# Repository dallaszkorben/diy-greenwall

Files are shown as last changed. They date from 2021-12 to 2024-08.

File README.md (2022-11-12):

# diy-greenwall

<table>
<tr>
<td>

[Before you start](Wiki/BeforeYouStart/beforeYouStart.md)
	
The Green Wall consist of many elements: 					
* Plants in the Balcony Planter Box mounted on the wall
* Irrigation system
* [Sensor Station](Wiki/SensorStation/sensorStation.md)s for measuring water level, temperature, humidity, air pressure
* Camera Station
* Lamp Pump Station
* [Central Access Point](Wiki/CentralAccessPoint/centralAccessPoint.md)
* [3D printed accessories](Wiki/3D/3d.md)
			
</td>
<td>
 
</td>
</tr>	
</table>

---

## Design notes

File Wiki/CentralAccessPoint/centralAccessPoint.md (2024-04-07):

# Central Access Point
The Central Access Point is running on a Raspberry Pi Zero W

## Network configuration

### Install necessary SWs

```sh
    $ sudo apt update
    $ sudo apt full-upgrade
```
```sh
    # dnsmasq - This program has extensive features, but for our purposes we are using it as a DHCP server for our WiFi AP.
    # hostapd - This program defines our AP’s physical operation based on driver configuration. 

    $ sudo apt-get install dnsmasq hostapd     	
```
Install grafana
Ubuntu and Debian(ARMv6): https://grafana.com/grafana/download/9.3.6?edition=enterprise&platform=arm
```sh
    sudo apt-get install -y adduser libfontconfig1 musl
    wget https://dl.grafana.com/enterprise/release/grafana-enterprise-rpi_9.3.6_armhf.deb
    sudo dpkg -i grafana-enterprise-rpi_9.3.6_armhf.deb
```
Config file: /etc/grafana/grafana.ini 

Install sqlite plugin
```sh
    grafana-cli plugins install frser-sqlite-datasource
```

Enable and Start grafana
```sh
    sudo /bin/systemctl enable grafana-server
    sudo /bin/systemctl start grafana-server
```

### Configurations

  * Check the existing network  
    This is what you can see before configuring
    ```sh
    pi@raspberrypi:~$ iw dev
    phy#0
        Unnamed/non-netdev interface
                wdev 0x4
                addr ba:27:eb:07:28:1f
                type P2P-device
                txpower 31.00 dBm
        Interface wlan0
                ifindex 2
                wdev 0x1
                addr b8:27:eb:ff:ff:ff
                ssid <YOUR HOME SSID> 
                type managed
                channel 1 (2437 MHz), width: 20 MHz, center1: 2437 MHz
                txpower 31.00 dBm
    ```
  * Configure dnsmasq  
Let’s call our new interface for AP to uap0
Here we can define the IP interval what we use for the nodes connecting to this AP. In this case it will be between 192.168.50.50 and 192.168.50.150
    ```sh
    pi@raspberrypi:~$ /etc/dnsmasq.conf
      interface=lo,uap0
      no-dhcp-interface=lo,wlan0
      bind-interfaces
      server=8.8.8.8
      domain-needed
      bogus-priv
      dhcp-range=192.168.50.50,192.168.50.150,24h
    ```

  * Configure hostapd  
Here the channel is hardcoded. There is a dynamic and better way to find out the right channel.
I’ll show it later
    ```sh
    pi@raspberrypi:~$ vi /etc/hostapd/hostapd.conf
      interface=uap0
      ssid=Central-Station-006 
      hw_mode=g 
      channel=1 
      macaddr_acl=0 
      auth_algs=1 
      ignore_broadcast_ssid=0 
      wpa=2 
      wpa_passphrase=viragfal 
      wpa_key_mgmt=WPA-PSK 
      wpa_pairwise=TKIP 
      rsn_pairwise=CCMP
    ```  

  * Configure wifi network interface file
    ```sh
     pi@raspberrypi:~$ vi /etc/wpa_supplicant/wpa_supplicant.conf

       ctrl_interface=DIR=/var/run/wpa_supplicant GROUP=netdev 
       update_config=1 

       network={ 
	       ssid="****" 
	       psk="****" 
	       key_mgmt=WPA-PSK 
	       id_str="AP1" 
       } 

       network={ 
	       ssid="****" 
	       psk="****" 
	       key_mgmt=WPA-PSK 
	       id_str="AP2" 
       }
 
  * Configure AP interface file
    ```sh       
     pi@raspberrypi:~$ vi /etc/network/interfaces
       source-directory /etc/network/interfaces.d 

       auto lo 
       auto uap0 
       auto wlan0 

       iface lo inet loopback 

       allow-hotplug uap0 
       iface uap0 inet static 
	       address 192.168.50.3 
	       netmask 255.255.255.0 
	       hostapd /etc/hostapd/hostapd.conf 

       allow-hotplug wlan0 
       iface wlan0 inet manual 
	       wpa-roam /etc/wpa_supplicant/wpa_supplicant.conf 

       iface AP1 inet dhcp 
       iface AP2 inet dhcp
     ```
  * Script to put all together
    ```sh
     pi@raspberrypi:~$ /usr/local/bin/hostapdstart.sh
       #!/bin/bash 

       mac=`sudo ifconfig |grep ether | sed 's/ether \([a-f0-9][a-f0-9]:[a-f0-9][a-f0-9]:[a-f0-9][a-f0-9]:[a-f0-9][a-f0-9]:[a-f0-9][a-f0-9]:[a-f0-9][a-f0-9]\).*/\1/g' | head -n 1` 

       sudo /sbin/iw phy phy0 interface add uap0 type __ap 
       sudo /bin/ip link set uap0 address $mac 

       sudo ifdown --force wlan0 
       sudo ifdown --force uap0 

       sudo ifup uap0 
       sudo ifup wlan0 

       # Fetch wifi channel 
       CHANNEL=`iwlist wlan0 channel | grep Current | sed 's/.*Channel \([0-9]*\).*/\1/g'` 
       export CHANNEL 

       # Create the config for hostapd 
       #cat /etc/hostapd/hostapd.conf.tmpl | envsubst > /etc/hostapd/hostapd.conf 

       # Uncomment the two following lines to get access to internet 
       #sysctl net.ipv4.ip_forward=1 
       #iptables -t nat -A POSTROUTING -s 192.168.50.0/24 ! -d 192.168.50.0/24 -j MASQUERADE 

       sudo systemctl restart hostapd 
       sleep 10 
       sudo systemctl restart dnsmasq 
       sleep 10 
       sudo systemctl restart dhcpcd
    ```
  * unmask hostapd
    ```sh
       pi@raspberrypi:~$ sudo systemctl unmask hostapd
       pi@raspberrypi:~$ sudo systemctl enable hostapd
       pi@raspberrypi:~$ sudo systemctl start hostapd
    ```
  * Run the script just after the reboot automatically  
    In the **crontab** file:
    ```sh
    root@raspberrypi:~$ crontab -e
       @reboot /usr/local/bin/hostapdstart.sh
    ```
  * Check the existing network after the configuration  
    You can see the new Interface: uap0
    ```sh
    root@raspberrypi:~# iw dev
       phy#0 
	       Unnamed/non-netdev interface 
		       wdev 0x3 
		       addr ba:27:eb:97:d5:fe 
		       type P2P-device 
		       txpower 31.00 dBm 
	       Interface uap0 
		       ifindex 3 
		       wdev 0x2 
		       addr b8:27:eb:97:d5:fe 
		       ssid Central-Station-006 
		       type AP 
		       channel 1 (2412 MHz), width: 20 MHz, center1: 2412 MHz 
		       txpower 31.00 dBm 
		       
               Interface wlan0
	               ifindex 2
                       wdev 0x1
                       addr b8:27:eb:ff:ff:ff
                       ssid <YOUR HOME SSID> 
                       type managed
                       channel 1 (2437 MHz), width: 20 MHz, center1: 2437 MHz
                       txpower 31.00 dBm		      
    ```

    ```sh
    root@raspberrypi:~# ip addr 
       1: lo: <LOOPBACK,UP,LOWER_UP> mtu 65536 qdisc noqueue state UNKNOWN group default qlen 1000 
	       link/loopback 00:00:00:00:00:00 brd 00:00:00:00:00:00 
	       inet 127.0.0.1/8 scope host lo 
		       valid_lft forever preferred_lft forever 
	       inet6 ::1/128 scope host
		       valid_lft forever preferred_lft forever 
       2: wlan0: <BROADCAST,MULTICAST,UP,LOWER_UP> mtu 1500 qdisc pfifo_fast state UP group default qlen 1000 
	       link/ether b8:27:eb:97:d5:fe brd ff:ff:ff:ff:ff:ff 
	       inet 192.168.0.103/24 brd 192.168.0.255 scope global dynamic wlan0 
		       valid_lft 1966sec preferred_lft 1966sec 
	       inet6 fdaa:bbcc:ddee:0:ba27:ebff:fe97:d5fe/64 scope global dynamic mngtmpaddr
		       valid_lft 2006054648sec preferred_lft 2006054648sec 
	       inet6 fe80::ba27:ebff:fe97:d5fe/64 scope link
		       valid_lft forever preferred_lft forever 
       3: uap0: <BROADCAST,MULTICAST,UP,LOWER_UP> mtu 1500 qdisc pfifo_fast state UP group default qlen 1000 
	       link/ether b8:27:eb:97:d5:fe brd ff:ff:ff:ff:ff:ff 
	       inet 192.168.50.3/24 brd 192.168.50.255 scope global uap0 
		       valid_lft forever preferred_lft forever 
	       inet6 fe80::ba27:ebff:fe97:d5fe/64 scope link
		       valid_lft forever preferred_lft forever

### Configuration hierarchy

```mermaid
graph LR
/var/spool/cron/crontabs/root --> /home/pi/Projects/diy-greenwall/Software/Central.AccessPoint-RaspberryPi/python/start
/var/spool/cron/crontabs/root --> /usr/local/bin/hostapdstart.sh

/usr/local/bin/hostapdstart.sh --> /etc/dnsmasq.conf
/usr/local/bin/hostapdstart.sh --> /etc/network/interfaces

/etc/network/interfaces --> /etc/hostapd/hostapd.conf
/etc/network/interfaces --> /etc/wpa_supplicant/wpa_supplicant.conf

  ```

---
## Controller software

### Create virtual environment for Python
```sh
pi@raspberrypi:~ $ sudo apt install python3-venv
pi@raspberrypi:~ $ cd /var/www/greenwall/python
pi@raspberrypi:/var/www/greenwall/python $ python3 -m venv env  
```

### Install prerequisites

  ```sh
  pi@raspberrypi:~ $ sudo apt-get install iptables-persistent

  pi@raspberrypi:~ $ sudo apt-get install libapache2-mod-wsgi-py3
 
  pi@raspberrypi:/var/www/greenwall/python $ source env/bin/activate
  (env) pi@raspberrypi:/var/www/greenwall/python/env/bin $ pip install requests
  (env) pi@raspberrypi:/var/www/greenwall/python/env/bin $ pip3 install python-dateutil 
  (env) pi@raspberrypi:/var/www/greenwall/python/env/bin $ python -m pip install flask
  (env) pi@raspberrypi:/var/www/greenwall/python/env/bin $ pip install Flask-Classful==0.15.0b1
  (env) pi@raspberrypi:/var/www/greenwall/python/env/bin $ pip3 install -U flask-cors
  (env) pi@raspberrypi:/var/www/greenwall/python/env/bin $ pip3 install rpi_lcd
  (env) pi@raspberrypi:/var/www/greenwall/python/env/bin $ pip3 install evdev
  (env) pi@raspberrypi:/var/www/greenwall/python/env/bin $ pip3 install psutil
  (env) pi@raspberrypi:/var/www/greenwall/python/env/bin $ pip install scipy --no-cache-dir
  (env) pi@raspberrypi:/var/www/greenwall/python/env/bin $ pip install matplotlib
  (env) pi@raspberrypi:/var/www/greenwall/python/env/bin $ pip3 install pandas
  (env) pi@raspberrypi:/var/www/greenwall/python/env/bin $ pip3 install natsort

  $ sudo apt-get install python3-sklearn python3-sklearn-lib  
  $ pip3 install opencv-python
  ```
### Clone the diy-greenwall project

First you should clone the diy-greenwall project from the GitHub.
 ```sh
  $ cd
  $ mkdir Projects
  $ git clone https://github.com/dallaszkorben/diy-greenwall.git
 ```
As you need only the hierarcy under the **diy-greenwall/Software/Central.AccessPoint-RaspberryPi** folder, on the Rasberry Pi, you can filter out the not necesary parts. But it is not mandatory to do

```sh
  $ cd diy-greenwall
  $ git  filter-branch -f --subdirectory-filter Software/Central.AccessPoint-RaspberryPi 
```

Under the **python** folder, you can see the following hierarchy of the python code:
  ```sh
  .
  ├── config
  │   ├── config.py
  │   ├── ini_location.py
  │   ├── __init.py__
  │   ├── permanent_data.py
  │   ├── property.py
  │   └── __pycache__
  │       ├── config.cpython-37.pyc
  │       ├── ini_location.cpython-37.pyc
  │       ├── permanent_data.cpython-37.pyc
  │       └── property.cpython-37.pyc
  ├── controlbox
  │   ├── controlbox.py
  │   ├── __init__.py
  │   └── __pycache__
  │       ├── controlbox.cpython-37.pyc
  │       └── __init__.cpython-37.pyc
  ├── exceptions
  │   ├── __init.py__
  │   ├── invalid_api_usage.py
  │   └── __pycache__
  │       └── invalid_api_usage.cpython-37.pyc
  ├── graph
  │   ├── graph_level.py
  │   ├── __init.py__
  │   └── __pycache__
  │       └── graph_level.cpython-37.pyc
  ├── greenwall.wsgi
  ├── ky040
  │   ├── __init__.py
  │   ├── ky040.py
  │   └── __pycache__
  │       ├── __init__.cpython-37.pyc
  │       ├── ky040.cpython-37.pyc
  │       └── KY040.cpython-37.pyc
  ├── restserver
  │   ├── endpoints
  │   │   ├── ep_info_functions.py
  │   │   ├── ep_info_graph.py
  │   │   ├── ep_info_timestamp.py
  │   │   ├── ep_level_add.py
  │   │   ├── ep.py
  │   │   ├── __init.py__
  │   │   ├── __pycache__
  │   │   │   ├── ep.cpython-37.pyc
  │   │   │   ├── ep_info_functions.cpython-37.pyc
  │   │   │   ├── ep_info_graph.cpython-37.pyc
  │   │   │   ├── ep_info_level.cpython-37.pyc
  │   │   │   ├── ep_info_timestamp.cpython-37.pyc
  │   │   │   ├── ep_info_trend.cpython-37.pyc
  │   │   │   ├── ep_level_add.cpython-37.pyc
  │   │   │   └── ep_level_read.cpython-37.pyc
  │   │   ├── representations.py
  │   │   └── ~toDelete
  │   │       └── ep_info_level.py
  │   ├── gradual_thread_controller.py
  │   ├── __init.py__
  │   ├── __pycache__
  │   │   ├── gradual_thread_controller.cpython-37.pyc
  │   │   ├── representations.cpython-37.pyc
  │   │   ├── view_info.cpython-37.pyc
  │   │   ├── view_level.cpython-37.pyc
  │   │   └── ws_greenwall.cpython-37.pyc
  │   ├── representations.py
  │   ├── view_info.py
  │   ├── view_level.py
  │   └── ws_greenwall.py
  ├── start.py
  └── utilities
      ├── __init.py__
      ├── __pycache__
      │   └── report.cpython-37.pyc
      └── report.py  
  ```

### Install Web server on Raspberry Pi
  Apache2 server should be installed and configured to allow browsers to connect and see the statuses of Sensors

  * Find the codes under **web-location/greenwall/** folder
    ```sh
    .
    └── greenwall
        ├── favicon.ico
        ├── /graph-images
        ├── /index.html
        └── /script
            ├── /jquery
            │   └── jquery-3.6.0.min.js
            └── /jquery-ui
                ├── AUTHORS.txt
                ├── /external
                │   └── /jquery
                │       └── jquery.js
                ├── images              
                ├── index.html
                ├── jquery-ui.css
                ├── jquery-ui.js
                ├── jquery-ui.min.css
                ├── jquery-ui.min.js
                ├── jquery-ui.structure.css
                ├── jquery-ui.structure.min.css
                ├── jquery-ui.theme.css
                ├── jquery-ui.theme.min.css
                ├── LICENSE.txt
                └── package.json
    ```
  * Copy the the whole folder to /var/www folder
  
    ```sh
    pi@raspberrypi:~$ cd web-location
    pi@raspberrypi:web-location$ cp -r greenwall /var/www/
    ```

  * Configure available Apach2 config file  
    Alternativaly you can copy the **green-wall.conf** file, found under the **web-config** folder to the **/etc/apache2/conf-available** folder on the Raspberry pi
    ```sh
    pi@raspberrypi:~$ touch /etc/apache2/conf-available/green-wall.conf
     
    WSGIRestrictStdout Off
    WSGIApplicationGroup %{GLOBAL}
    <VirtualHost *:80>
        ServerAdmin webmaster@greenwall.com
        ServerName www.greenwallsite.com
        ServerAlias greenwallsite.com

        ErrorLog /var/www/greenwall/logs/error.log
        CustomLog /var/www/greenwall/logs/access.log combined

        WSGIDaemonProcess greenwall user=pi group=pi threads=5 python-home=/var/www/greenwall/python/env
        WSGIProcessGroup greenwall
        WSGIScriptAlias / /var/www/greenwall/python/greenwall.wsgi    

        <IfModule dir_module>
            DirectoryIndex index.html
        </IfModule>

        Alias /greenwall/ /var/www/greenwall/
        <Directory /var/www/greenwall>
            Order allow,deny
            Allow from all
        </Directory>

    </VirtualHost>
    ```

  * Configure enabled Apach2 config file
    ```sh
    pi@raspberrypi:~$ ln -s /etc/apache2/conf-available/green-wall.conf /etc/apache2/conf-enabled/green-wall.conf      
    ```
  
  * Install mod_wsgi
    ```sh
    pi@raspberrypi:~$ sudo apt-get install libapache2-mod-wsgi python-dev
    ```

  * Enable mod_wsgi
    ```sh
    pi@raspberrypi:~$ sudo a2enmod wsgi 
    ```
      
  * Restart Apach2 service
    ```sh
    ~~pi@raspberrypi:~$ sudo /etc/init.d/apache2 restart~~ 
    pi@raspberrypi:~$ sudo systemctl restart apache2      
    ```

### Services on PI
#### CAM
```mermaid
sequenceDiagram
participant Cam
participant PI
participant WEB browser

    loop CamRegister
        Cam->>PI: POST /cam/register
        PI->>PI: register
    end

    loop AutomaticSaveFrame
        Cam->>PI: POST /cam/save/frame/camId/<camId>
        PI->>PI: save file
    end

    loop GetRegisteredCams
        WEB browser->>PI: GET /cam/captureList
        PI->>WEB browser: gives back the registered cams
    end

    loop SaveCaptureByRequest
        WEB browser->>PI: GET /cam/capture/url
        PI->>Cam: GET /capture
        Cam->>Cam: take photo
        Cam->>PI: send back photo
        PI->>WEB browser: gives back the url to the photo 
    end

    loop GenerateVideoFromFrames
        WEB browser->>PI: POST /cam/construct/video {camId,startDate,endDate,fps}
        PI->>PI: construct the video in the background
    end
  ```

#### LAMP-PUMP
#### SENSORS

### Port forwarding
  Why do we need it?
  Because in  development/test phase I use the stand alone WSGI server to receive REST requests from the Sensor Stations and Control Stations. The stand alone WSGI server uses port 5000.
  
  But later, I use the integrated WSGI in the Apache server, instead of the stand alone WSGI. That means, the port changes to 80. But I do not want to change the code all the time in the Station modules, when I change the WSGI. 
To make it work in both case I have to do a port forwarding. If the Central Controler Unit receive a rest request to port 5000, it should be mapped to port 80 instead.

```sh
    root@raspberrypi:~# echo "1" /proc/sys/net/ipv4/ip_forward
    root@raspberrypi:~# iptables -t nat -A PREROUTING -p tcp -d 192.168.50.3 --dport 5000 -j DNAT --to-destination 192.168.50.3:80
    root@raspberrypi:~# iptables -t nat -A POSTROUTING -j MASQUERADE
```

The firewall should look like this:

```sh
    root@raspberrypi:~# iptables -t nat -L --line-numbers
    Chain PREROUTING (policy ACCEPT)
    num  target     prot opt source               destination         
    1    DNAT       tcp  --  anywhere             192.168.50.3         tcp dpt:5000 to:192.168.50.3:80

    Chain INPUT (policy ACCEPT)
    num  target     prot opt source               destination         

    Chain POSTROUTING (policy ACCEPT)
    num  target     prot opt source               destination         
    1    MASQUERADE  all  --  anywhere             anywhere            

    Chain OUTPUT (policy ACCEPT)
    num  target     prot opt source               destination         
```

Unfortunatelly this settings will disappear after a reset, so you have to make it persistent.
```sh
    root@raspberrypi:~# /sbin/iptables-save > /etc/iptables/rules.v4
    root@raspberrypi:~# cat /etc/iptables/rules.v4
    
    # iptables-persisten was already installed
    # make sure the service is enabled
    root@raspberrypi:~# sudo systemctl is-enabled netfilter-persistent.service
    enabled
    
    # if it is not, then enable it
    root@raspberrypi:~# sudo systemctl enable netfilter-persistent.service
    
    # get status
    sudo systemctl status netfilter-persistent.service

```

---
## ky040 - rotary encoder
  
  To enable/configure the rotary-encoder device tree overlay, simply put something like the following into **/boot/config.txt** (with the encoder connected to pins **5** and **6** on the Raspberry Pi)
  While you’re at it, you might also want to add the middle button as a key (mine is connected to pin **13**):

  * enable rotary encoder
    ```sh       
    pi@raspberrypi:~$ vi /boot/config.txt
       dtoverlay=rotary-encoder,pin_a=5,pin_b=6,relative_axis=1
       dtoverlay=gpio-key,gpio=13,keycode=28,label="ENTER"       
    ```
  After a reboot you’ll have a new device in **/dev/input/** for the rotary encoder. You can use the **evtest** tool (as in evtest /dev/input/event0) to look at the events it generates and confirm that it reacts perfectly to every turn of the encoder, without missing a movement or confusing the direction.

  * Here is an example, shows how to read the output of the rotary encoder.
    ```python
    from __future__ import print_function
    import evdev
    import select

    devices = [evdev.InputDevice(fn) for fn in evdev.list_devices()]
    devices = {dev.fd: dev for dev in devices}
    value = 1
    print("Value: {0}".format(value))
    done = False
    
    while True:
        r, w, x = select.select(devices, [], [])
        for fd in r:
            for event in devices[fd].read():
                event = evdev.util.categorize(event)
                if isinstance(event, evdev.events.RelEvent):
                    value = value + event.event.value
                    print("Value: {0}".format(value))
                elif isinstance(event, evdev.events.KeyEvent):
                    if event.keycode == "KEY_ENTER" and event.keystate == event.key_up:
		        print("Enter")
    ```

---
## 2x16 LCD display
  
  * In the Raspberry Pi run the "Raspberry Pi Configuration" application and undert the "Interfaces" tab, **Enable** the I2C
  * Connect the pins of LCD display to the corresponding pins of RP
    * GND -> GND
    * VCC -> 5V
    * SDA -> SDA1
    * SCL -> SCL1
  * Check th eaddress of the I2C box on the RP
    ```sh         
    pi@raspberrypi:/var/www $ i2cdetect -y 1
         0  1  2  3  4  5  6  7  8  9  a  b  c  d  e  f
    00:          -- -- -- -- -- -- -- -- -- -- -- -- -- 
    10: -- -- -- -- -- -- -- -- -- -- -- -- -- -- -- -- 
    20: -- -- -- -- -- -- -- 27 -- -- -- -- -- -- -- -- 
    30: -- -- -- -- -- -- -- -- -- -- -- -- -- -- -- -- 
    40: -- -- -- -- -- -- -- -- -- -- -- -- -- -- -- -- 
    50: -- -- -- -- -- -- -- -- -- -- -- -- -- -- -- -- 
    60: -- -- -- -- -- -- -- -- -- -- -- -- -- -- -- -- 
    70: -- -- -- -- -- -- -- --                       
    ```

## Wiring

```sh
                                         
   Raspberry PI   LCD    Rotary                                         
   ____________________________                                         
   pin Function                                         
     3 GPIO 2     SDA                                               
     5 GPIO 3     SCL                                                        
     4 5V         VCC                                              
     9 GND        GND                                   Rotary encoder
                                                     _______________
     2 5V                +                          /        _       \
     6 GND               GND                       |     /       \    |
    29 GPIO 5            CLK                       |                  |
    31 GPIO 6            TD                        |    |    o    |   |
    33 GPIO 13           SW                        |                  |
                                                   |     \       /    |
                                                   |         -        |
                                                   |   C           G  |
     Raspberry PI W Zero                           |   L  T  S     N  |
    __________________                             |   K  D  W  +  D  |
   /     |      |     \                            |                  |
  |      |      |      |                           |   o  o  o  o  o  |
  |       ------       |                            \__|__|__|__|__|_/
  |             1  2   |                               |  |  |  |  |
  |             o  o-----------------------------------|--|--|--'  |
  | .-----------o  o------------------------.          |  |  |     |
  | |  .--------o  o-----------------------------------|--|--|-----'
  | | |         o  o   |                    |          |  |  |
  | | | .-------o  o   |             .-----------------'  |  |
  | | | |       o  o   |             |      |             |  |
  | | | |       o  o   |           .----------------------'  |
  | | | |       o  o   |           | |      |                |
  | | | |       o  o   |         .---------------------------'
  | | | |       o  o   |         | | |      |
  | | | |       o  o   |         | | |      |
  | | | |       o  o   |         | | |      |
  | | | |       o  o   |         | | |      |
  | | | |       o  o   |         | | |      |          LCD Display
  | | | | .-----o  o   |         | | |      |     ____________________
  | | | | | .---o  o   |         | | |      |    /      S  S  V  G    \ 
  | | | | | | .-o  o   |         | | |      |   |       C  D  C  N     | 
  | | | | | | | o  o   |         | | |      |   |       L  A  C  D     |
  | | | | | | | o  o   |         | | |      |   |                      |
  | | | | | | | o  o   |         | | |      |   |       o  o  o  o     |
  | | | | | | | 39 40  |         | | |      |   |       |  |  |  |     |
   \|_|_|_|_|_|_______/          | | |      |    \______|__|__|__|____/
    | | | | | |                  | | |      |           |  |  |  |
    | | | | | `------------------' | |      |           |  |  |  |
    | | | | `----------------------' |      |           |  |  |  |
    | | | `--------------------------'      |           |  |  |  |
    | | |                                   |           |  |  |  |
    | | |                                    `----------|--|-'   |
    | | |                                               |  |     |
    | | `-----------------------------------------------|--|----'
    | `-------------------------------------------------'  | 
    `------------------------------------------------------'
```

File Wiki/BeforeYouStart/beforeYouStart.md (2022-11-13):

# Before you start

I'm working on Ubuntu 22.04.1 LTS 
You need to install some things and fix some other things to be able to start

## Arduino

### Install Arduino

```sh
$ sudo apt update
$ sudo apt upgrade
$ mkdir arduino
$ cd arduino/
$ wget https://downloads.arduino.cc/arduino-1.8.15-linux64.tar.xz
$ tar -xvf ./arduino-1.8.15-linux64.tar.xz
$cd arduino-1.8.15/
$ sudo ./install.sh
```

### Add necessary Boards

File > Preferences > Additional Boards Manager URLs:

https://dl.espressif.com/dl/package_esp32_index.json,https://arduino.esp8266.com/stable/package_esp8266com_index.json

### Install necessary Libraries

Tools > Manager Libraries

 * BMP180MI
 * ArduinoJson
 * DHT sensor library
 * Preferences
 * Time

### Fix ttyUSB error

It might happen that when you upload a sketch - after you have selected your board and the serial port -, you get an error Error opening serial port ... If you get this error, you need to set serial port permission.

Check the serial port permission:

```sh
$ ls -l /dev/ttyUSB0
crw-rw---- 1 root dialout 188, 0 Nov 12 21:36 /dev/ttyUSB0
```

You need to add your user to the group

`<username>`: is your Linux user name.

```sh
sudo usermod -a -G dialout <username>
```

You will need to log out and log in again for this change to take effect.
And then you can start the arduino UI again

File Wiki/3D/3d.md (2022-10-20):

# 3D printed accessories

## Flower Container

<p float="left">
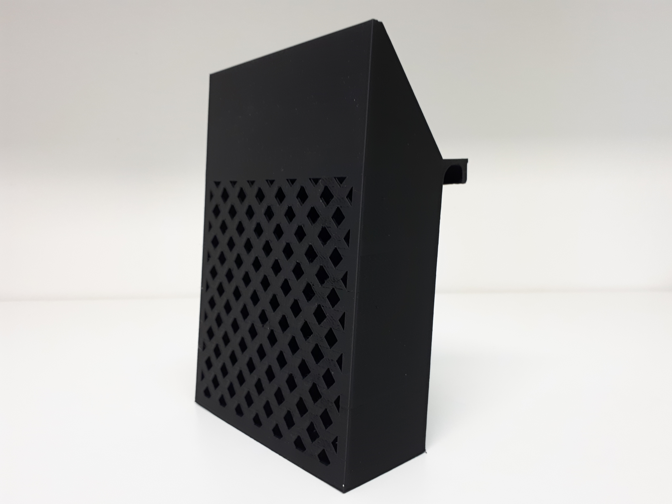
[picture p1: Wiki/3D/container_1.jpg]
    
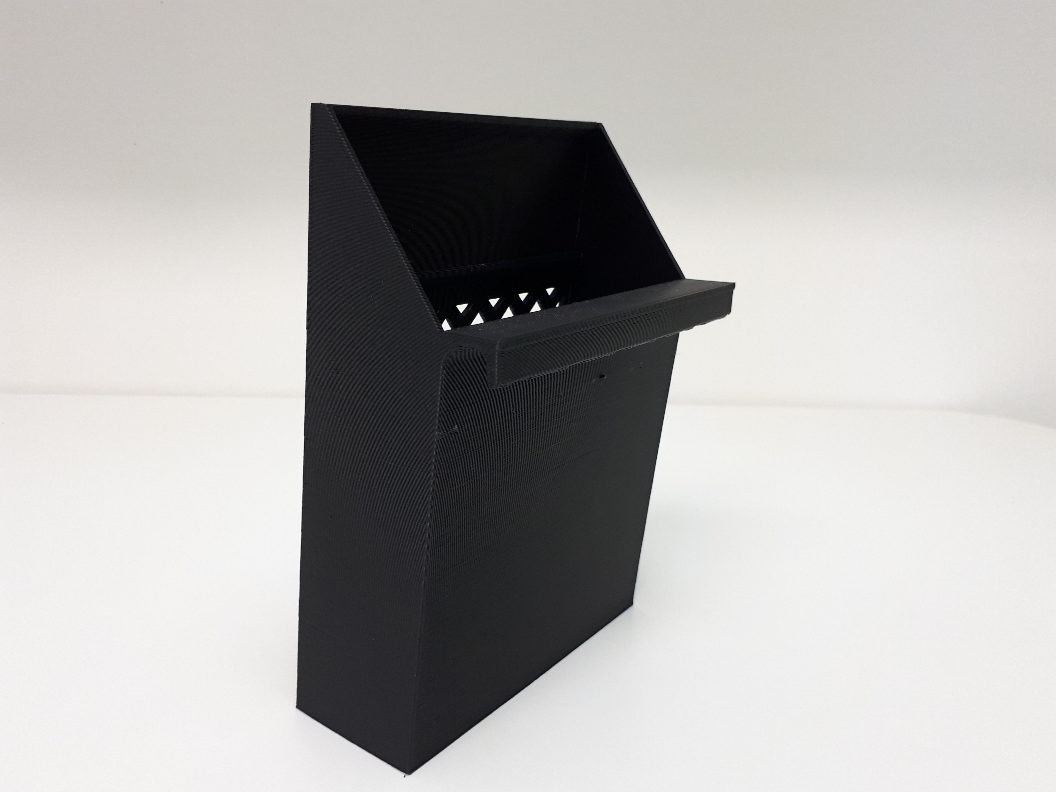
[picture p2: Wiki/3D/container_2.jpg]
    
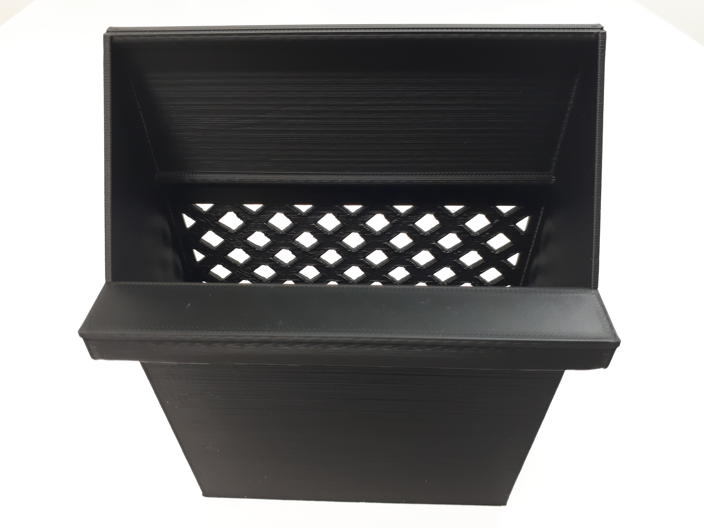
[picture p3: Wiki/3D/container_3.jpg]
    
</p>

## Overflow

## Sensor Station
<p float="left">
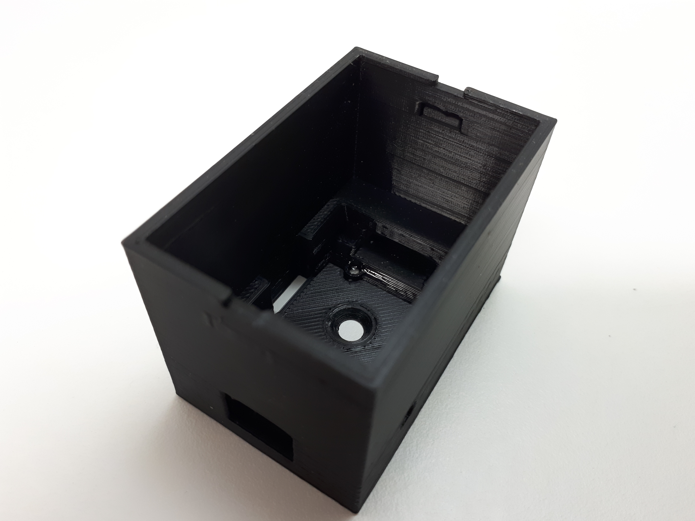
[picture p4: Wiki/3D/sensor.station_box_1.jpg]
    
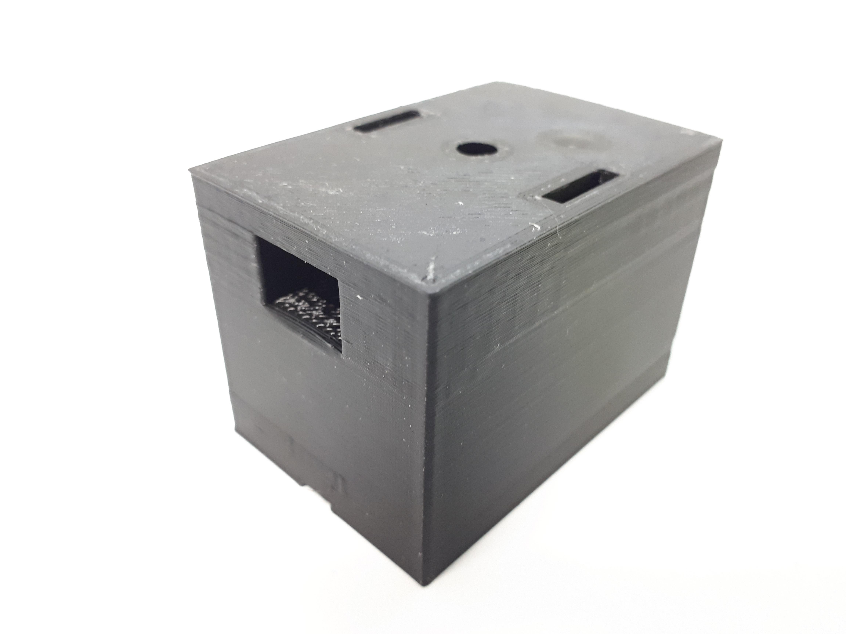
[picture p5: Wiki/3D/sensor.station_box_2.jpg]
    
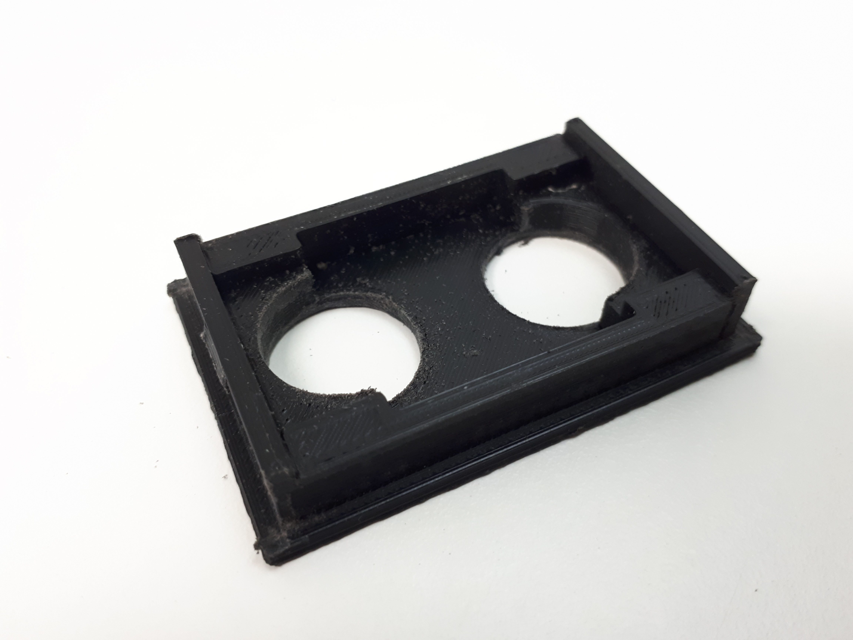
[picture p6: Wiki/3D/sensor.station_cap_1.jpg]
    
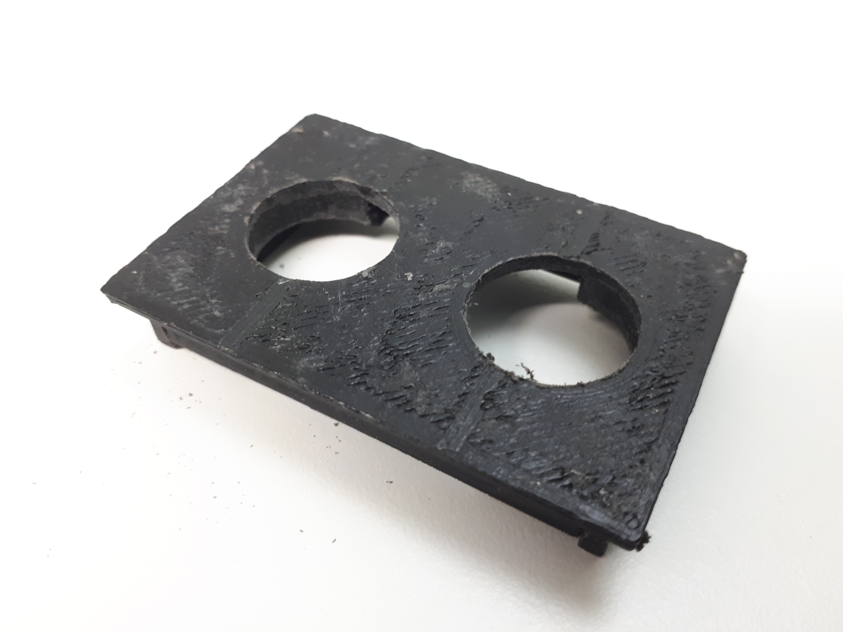
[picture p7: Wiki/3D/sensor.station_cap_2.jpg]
    
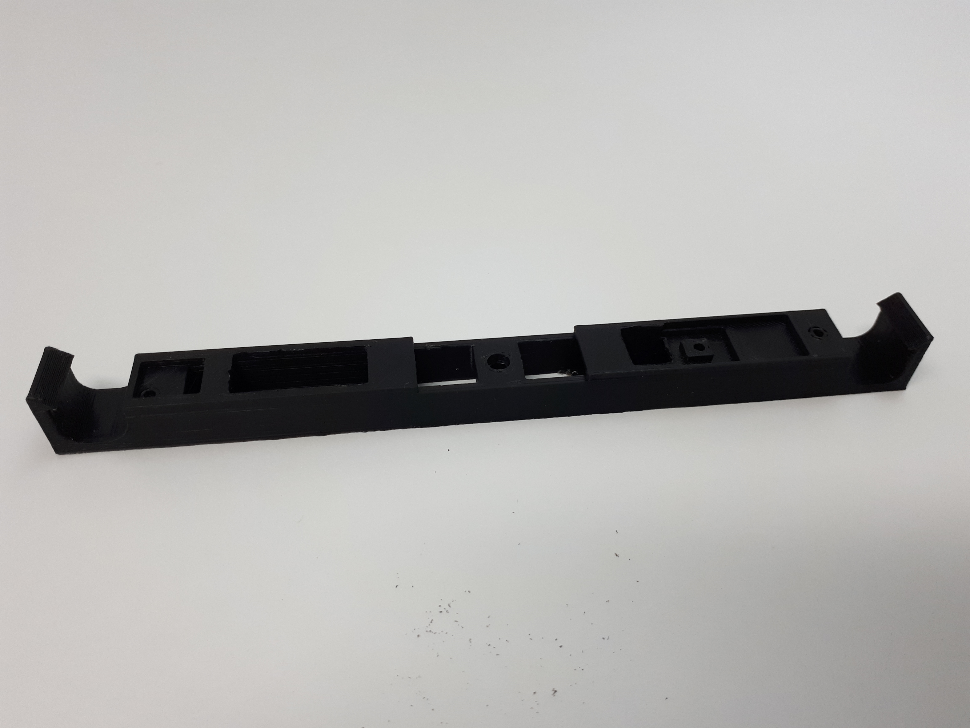
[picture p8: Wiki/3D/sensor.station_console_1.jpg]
    
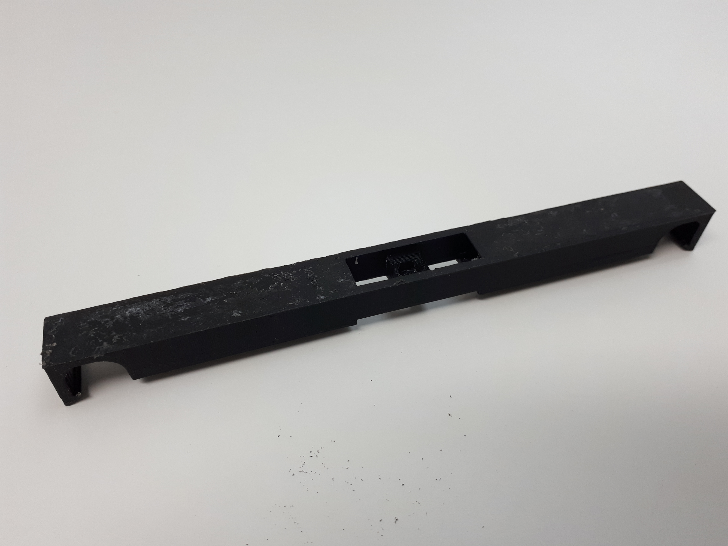
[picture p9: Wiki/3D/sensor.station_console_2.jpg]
    
</p>
<p float="left">
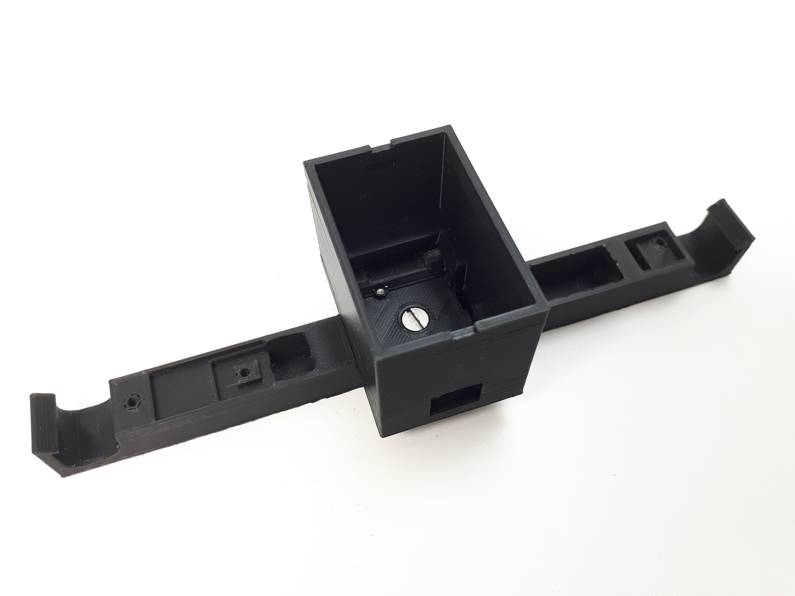
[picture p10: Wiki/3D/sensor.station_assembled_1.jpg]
    
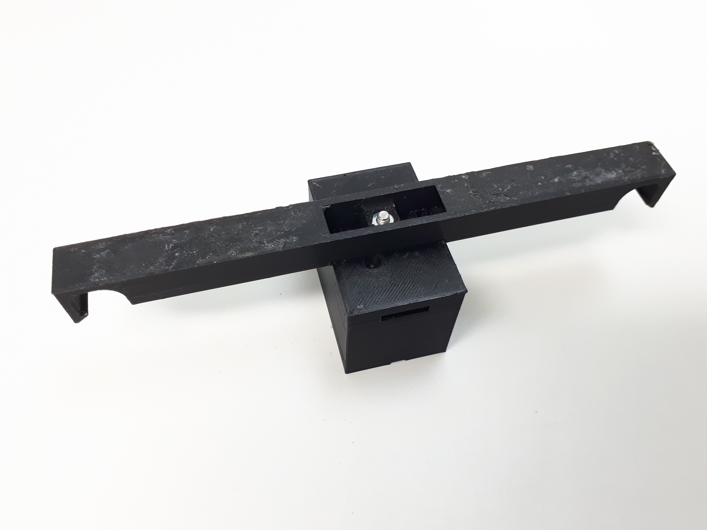
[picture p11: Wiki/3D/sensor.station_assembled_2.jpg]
    
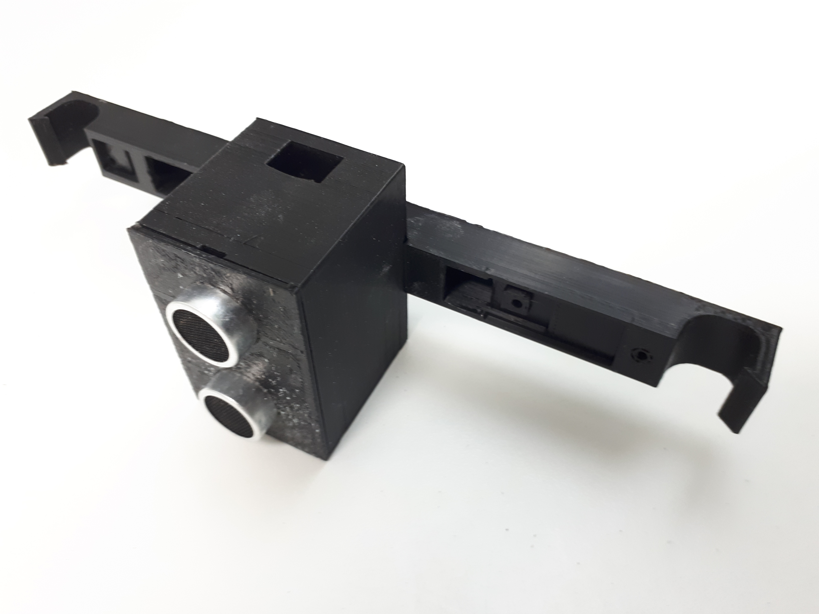
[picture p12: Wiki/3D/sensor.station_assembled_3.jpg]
    
</p>

## Cam Station

## Lamp/Pump Station

## Central Access Point

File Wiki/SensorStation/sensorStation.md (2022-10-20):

# Sensor Station
The Sensor Station units are ESP12F modules with connected sensors.  
The code is written in C under Arduino.  
The code does 4 main things:
 * Runs a Web Server and serves the requests
 * Periodically makes measurements on the sensors, calculates an average value and stores those values. In one loop it makes measurement only on one sensor to reduce time delay.
 * Periodically (configurable) sends the stored values to the server, and then reset the stored values
 * For safety's sake, the module periodically (configurable) resets itself.

## Needed libraries in Arduino

 * DHT sensor library
 * BMP180MI

## Used sensors

 * DHT22 - Temperature/Humidity sensor  
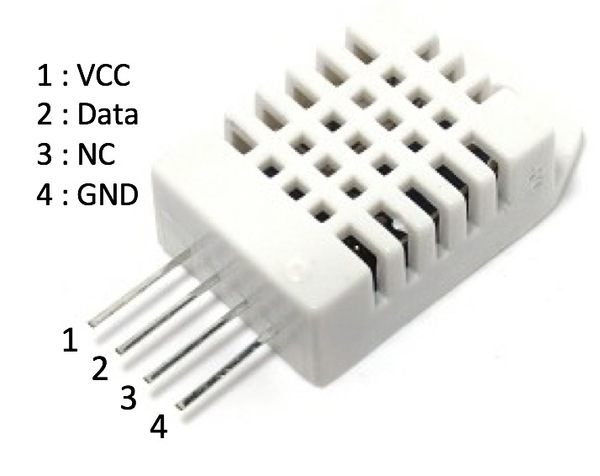
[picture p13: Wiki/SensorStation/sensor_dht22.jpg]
    
 * BMP180 - Barometric Pressure/Temperature sensor  
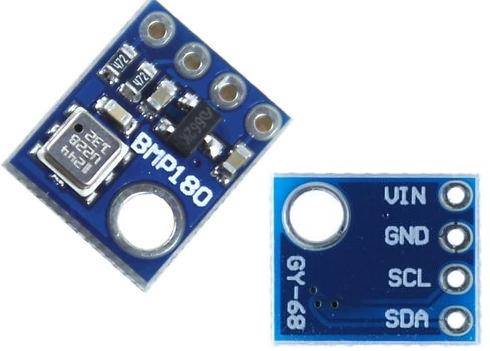
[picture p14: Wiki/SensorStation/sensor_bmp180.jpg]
    
 * HCSR04 - Ultrasonic sensor to measure water level  
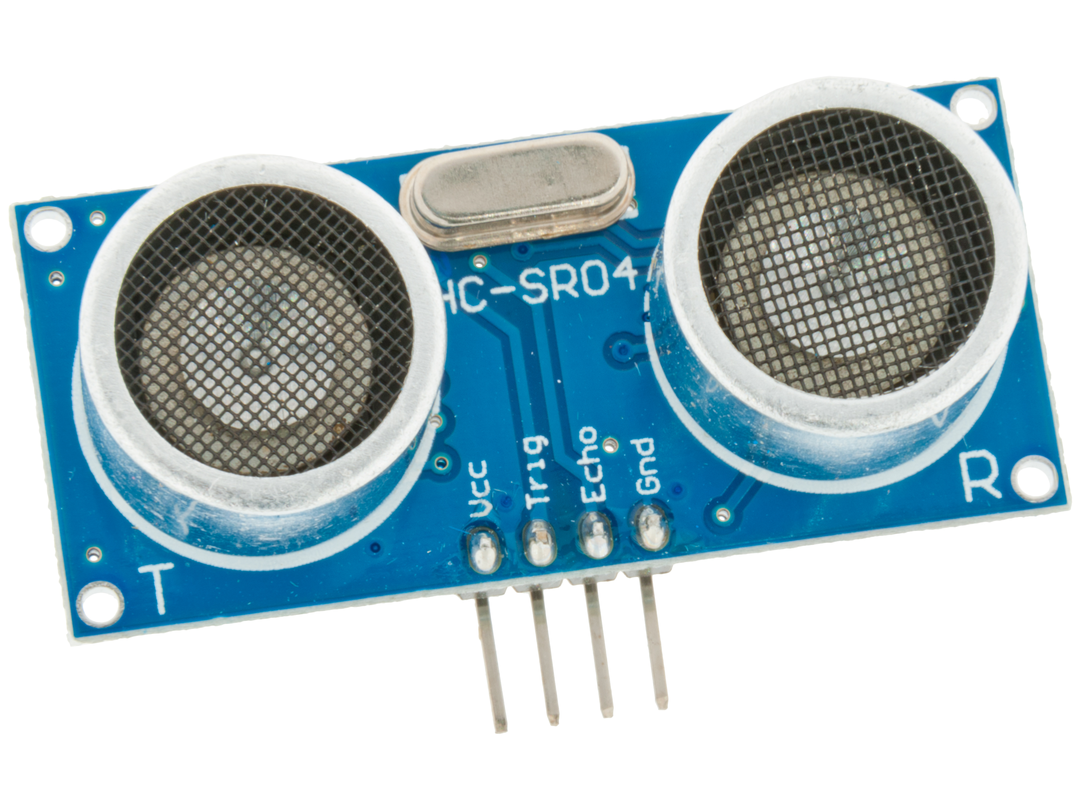
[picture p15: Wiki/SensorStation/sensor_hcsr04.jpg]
    

## WebServer entry points
You can send direct REST requests to the SensorStation

### GET /configure
Gives back the configuration collection in json format
```sh
pi@raspberrypi:~ $ curl -s --request GET http://192.168.50.101:80/configure
{"stationId": "default","sensorTempHumOutGPIO": "0","sensorDistanceTrigGPIO": "12","sensorDistanceEchoGPIO": "14","intervalReportMillis": "600300","intervalRegisterMillis": "120600",}
```

### POST /configure
Sets values of the configuration collection.
You can provide all values or a sub-set of the values in the json format
```sh
curl  --header "Content-Type: application/json" --request POST --data '{"stationId": "default","sensorTempHumOutGPIO": "0","sensorDistanceTrigGPIO": "12","sensorDistanceEchoGPIO": "14","intervalReportMillis": "600300","intervalRegisterMillis": "120600",}' http://192.168.50.101:80/configure
```

### GET /temperature
Measure the temperature - taking 1 sample only - on all connected termometer (BMP180/DHT22), and gives back the calculated average value in json format
If no termometer sensor connected, it gives back EMPTY ("") value
```sh
pi@raspberrypi:~ $ curl -s --request GET http://192.168.50.101:80/temperature
{"temperature": "24.15"}
```

### GET /humidity
Measure the humidity (DHT22) - taking 1 sample only - and gives back it in json format.
If the humidity sensor is not connected, it gives back EMPTY ("") value
```sh
pi@raspberrypi:~ $ curl -s --request GET http://192.168.50.101:80/humidity
{"humidity": "45.00"}
```

### GET /pressure
Measure the pressure (BMP180) - taking 1 sample only - and gives back it in json format.
If the pressure sensor is not connected, it gives back EMPTY ("") value
```sh
pi@raspberrypi:~ $ curl -s --request GET http://192.168.50.101:80/pressure
{"pressure": "102545.00"}
```

### GET /distance
Measure the distance (HCSR04) - taking 1 sample only - and gives back it in json format.
If the  sonar sensor is not connected, it gives back EMPTY ("") value
```sh
pi@raspberrypi:~ $ curl -s --request GET http://192.168.50.101:80/distance
{"distance": "7.21"}
```

### GET /all/actual
Measures all measurable quntities, from the connected sensors, and gives back the results in one request
```sh
pi@raspberrypi:~ $ curl -s --request GET http://192.168.50.101:80/all/actual
{"temperature": "24.20","humidity": "45.70","pressure": "102549.00","distance": "7.62",}
```

### GET /all/aggregated
The ESP module continously collects all measurable quantities from the sensors, calculates the average values and store them.
This request gives back the stored average values. The point is that in this request there is NO measurement.
```sh
pi@raspberrypi:~ $ curl -s --request GET http://192.168.50.101:80/all/aggregated
{"temperature": "24.17","humidity": "45.92","pressure": "102546.05","distance": "7.27",}
```

## Wiring

```sh
ESP12F       | DHT22  BMP180  HCSR04                           
             |                                                       
pin Function |                                       
_____________|______________________
 D3 GPIO 0   | OUT                                               
             |                                                         
 D2 GPIO 4   |        SDA                                       
 D1 GPIO 5   |        SCL                     
             |                                
 D5 GPIO 14  |                ECHO            
 D6 GPIO 12  |                TRIG            

    HCSR04                      ESP12F                             BMP180
 .----------.           .---------------------.
 |          |           |    || |_| |_| |     |               .--------------.
 |          |           | o  ||         |TX o |               |              |
 |          |           | o   .--------.    o |               | o VIN     O  |
 |   GND  o------.      | o   |        |    o |       .---------o GND        |
 |   Echo o---------------o D5|        |D01 o---------|---------o SCL  .---. |
 |   Trig o---------------o D6|        |D02 o---------|---------o SDA  |   | |
 |   Vcc  o----. |      | o   |        |D03 o---------|--.    |        `---' |
 |          |  | |      | o   .--------'GND o---------.  |    `--------------'
 |          |  | | .------o 3.3V        5V  o----.    |  |
 |          |  | | |    |                     |  |    |  |         DHT22
 |          |  | | |    |                     |  |    |  |    . -------------.
 `----------'  | | |    `---------------------'  |    |  |    |           |   \
               | | `-----------------------------|----|--|------o +       |    \
               `---------------------------------'    |  `------o Out     | O  | 
                 `------------------------------------`---------o -       |    /
                                                              |           |   /
                                                              `--------------'

```

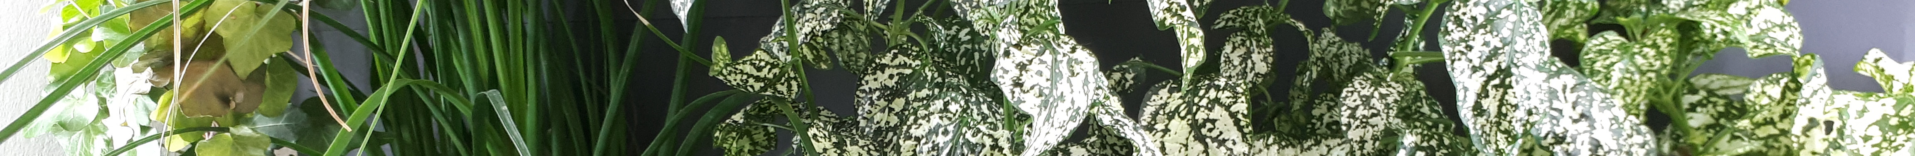
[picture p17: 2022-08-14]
Software/Central.AccessPoint-RaspberryPi/var/www/greenwall/header.jpg

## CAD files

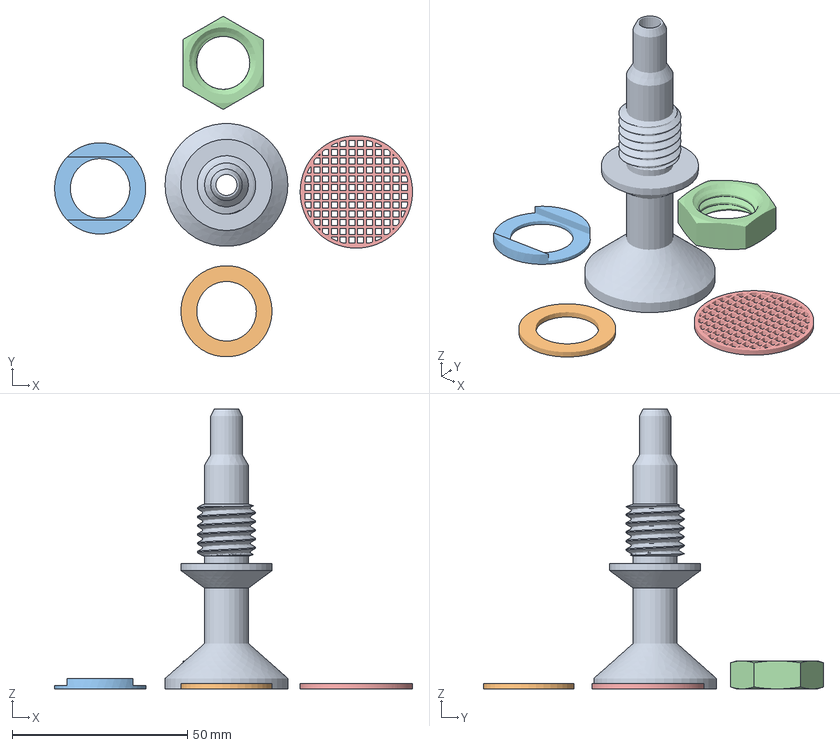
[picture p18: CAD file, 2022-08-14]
3D/STL/owerflow/overflow.plug.full.amf
102.0 x 97.0 x 79.7 mm
Nut-R=9,003

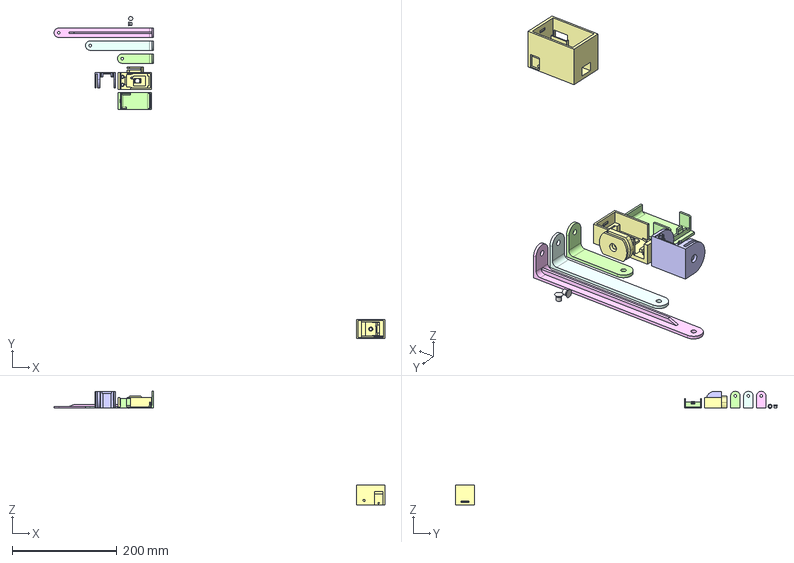
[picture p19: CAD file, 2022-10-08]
3D/FREECAD/camera/camera.wroover.nested.FCStd
631.3 x 614.5 x 216.7 mm

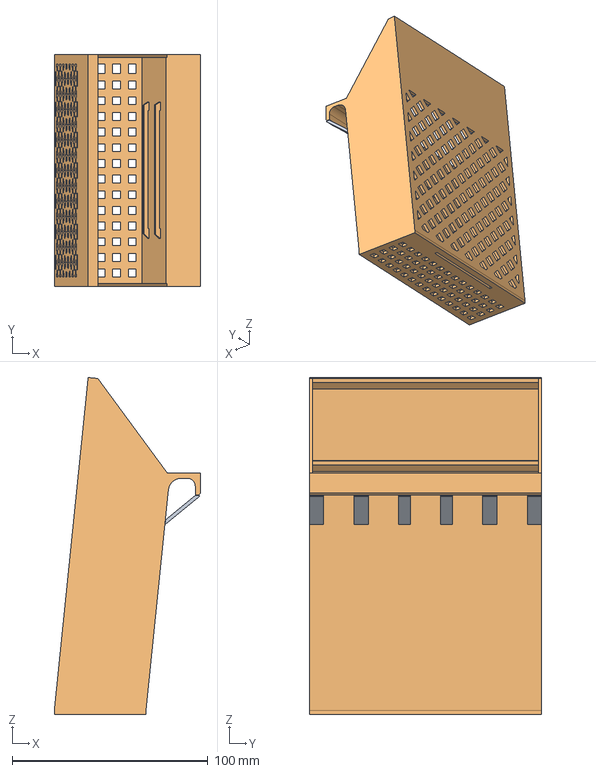
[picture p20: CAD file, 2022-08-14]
3D/FREECAD/container/container-vertical.FCStd
74.8 x 118.7 x 172.0 mm

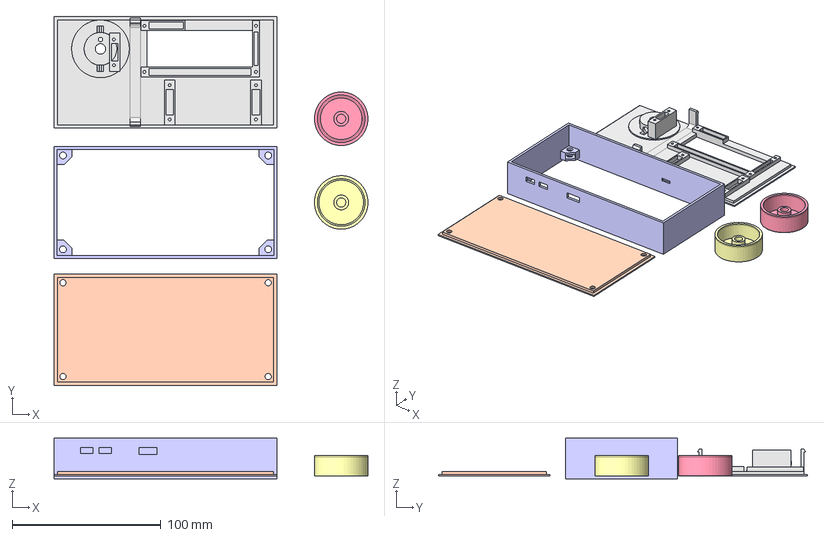
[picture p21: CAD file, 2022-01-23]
3D/FREECAD/control.box/controlbox.FCStd
211.1 x 248.0 x 27.5 mm

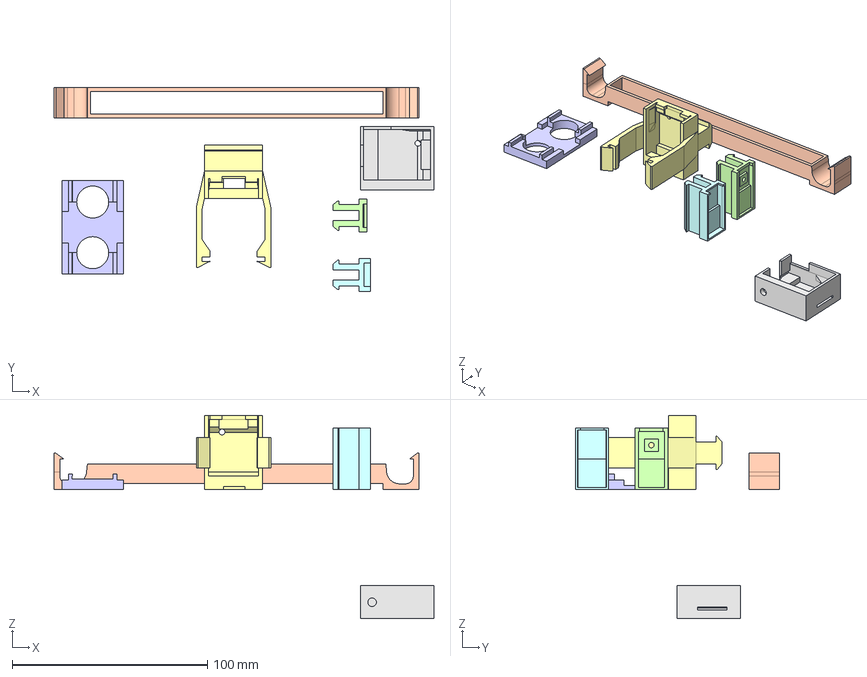
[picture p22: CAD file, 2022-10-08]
3D/FREECAD/hanger.station.V2.FCStd
194.8 x 104.6 x 104.1 mm
Rectangle002

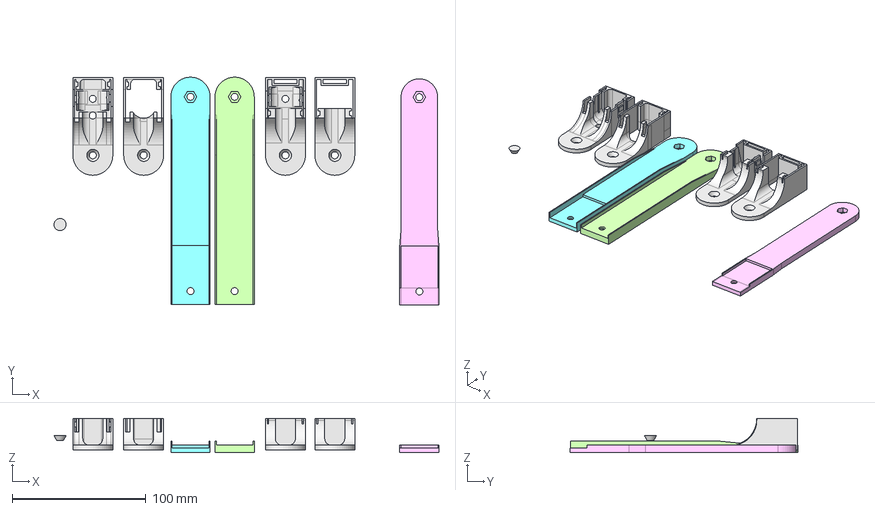
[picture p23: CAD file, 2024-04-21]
3D/FREECAD/lamp/lamp.hanger.FCStd
288.0 x 170.3 x 25.5 mm
Reversed_Closed
Console_Nut
Console_Screw
Straight_Closed
Slice.0

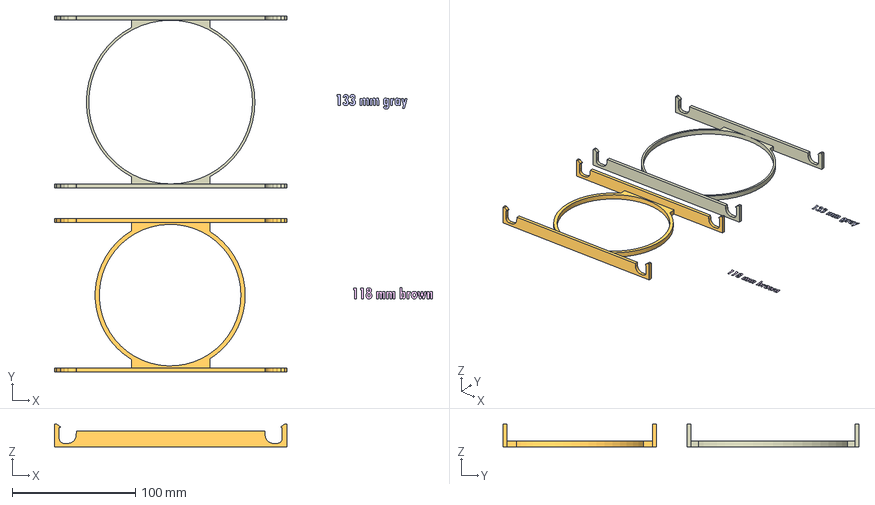
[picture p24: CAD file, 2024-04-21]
3D/FREECAD/round.container.hanger/round.container.hanger.FCStd
307.5 x 289.3 x 18.7 mm
ShapeString
ShapeString001

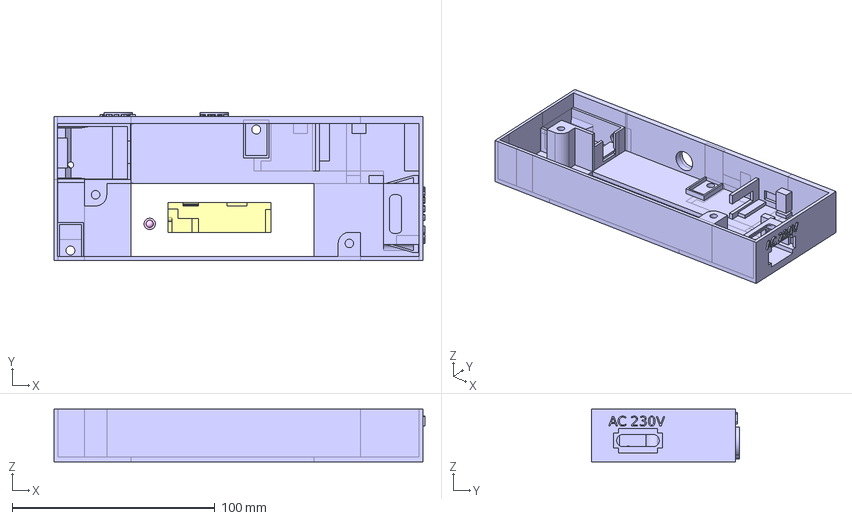
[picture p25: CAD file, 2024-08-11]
3D/FREECAD/station.lamp.1x42-YL401000/tmp.FCStd
182.8 x 73.1 x 26.0 mm
Cut008 (Solid)

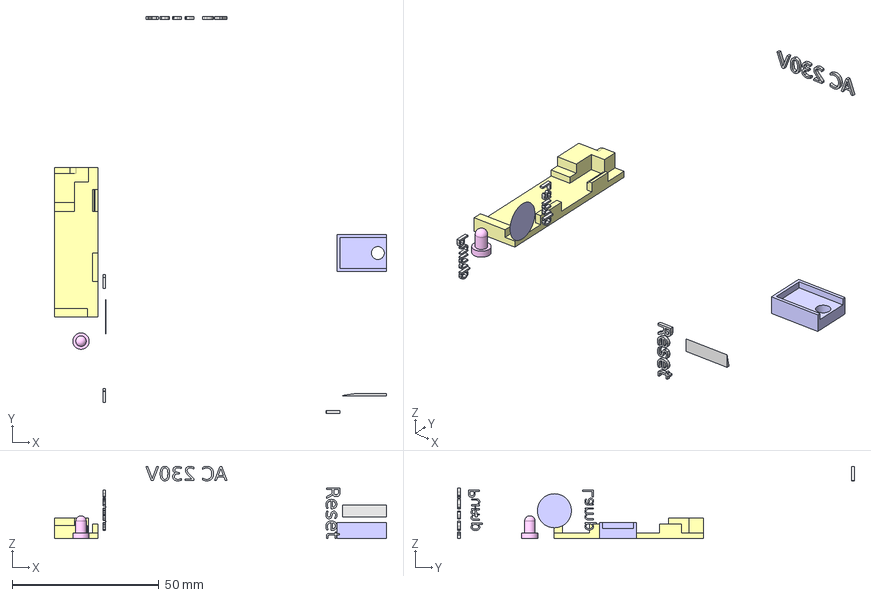
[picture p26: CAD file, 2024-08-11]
3D/FREECAD/station.lamp.pump/station.lamp.pump.100W.FCStd
113.2 x 135.2 x 24.6 mm
Slice.2
Text001
Circle

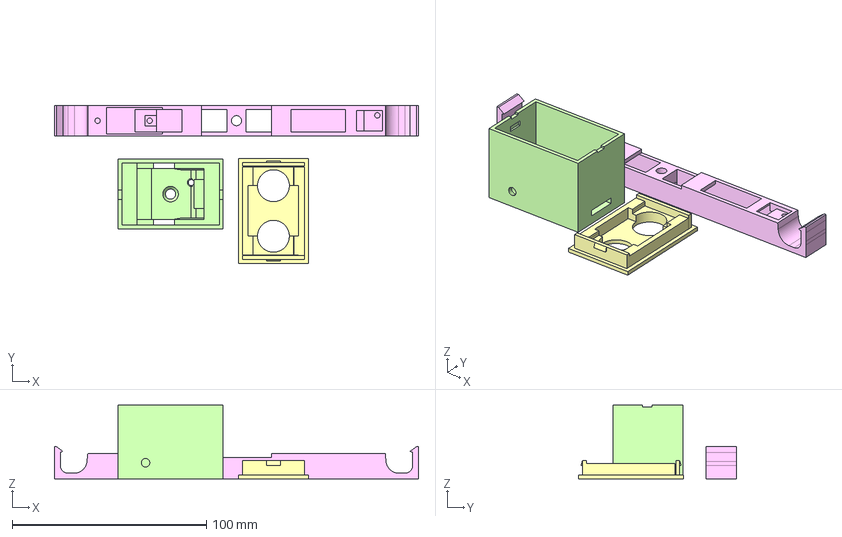
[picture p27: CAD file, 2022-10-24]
3D/FREECAD/station.sensor/station.sensor.V2.FCStd
187.2 x 81.2 x 38.0 mm

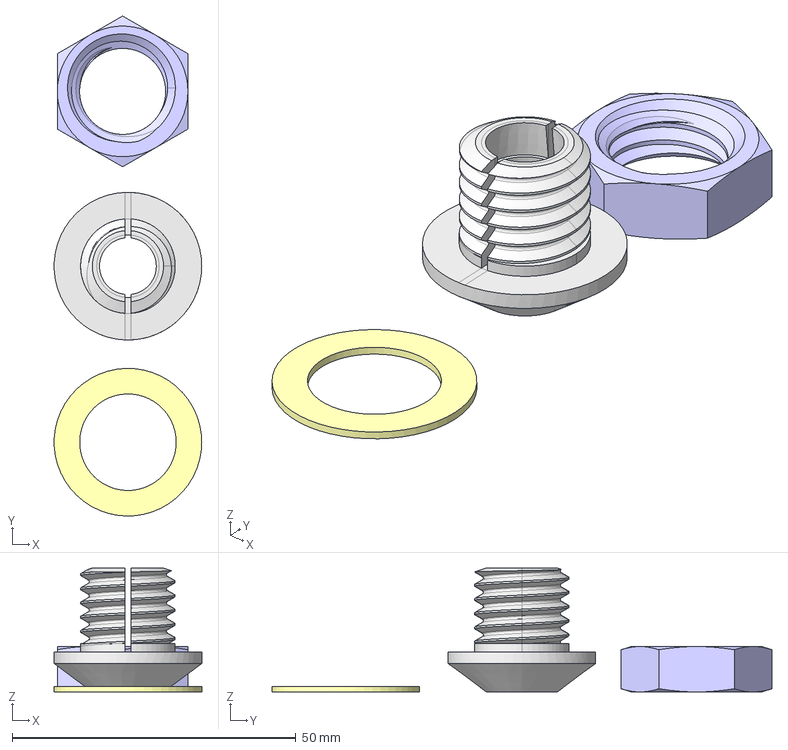
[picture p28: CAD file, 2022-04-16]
3D/FREECAD/water.tank/water_tank.FCStd
26.0 x 88.0 x 21.8 mm
Nut-R=9,2

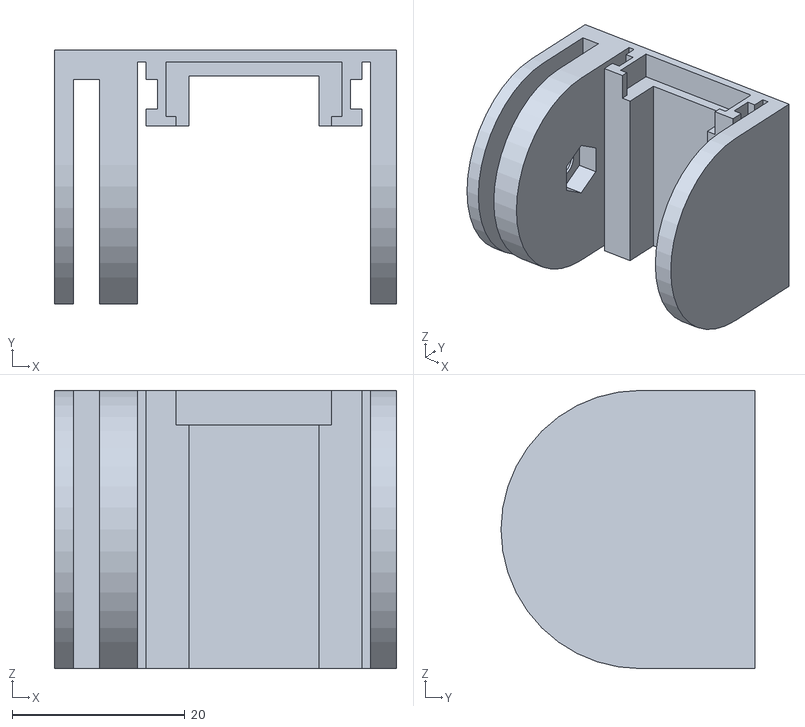
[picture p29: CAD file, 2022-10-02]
3D/STL/camera/camera.wroover.nested.rail_straight.stl
39.6 x 29.4 x 32.2

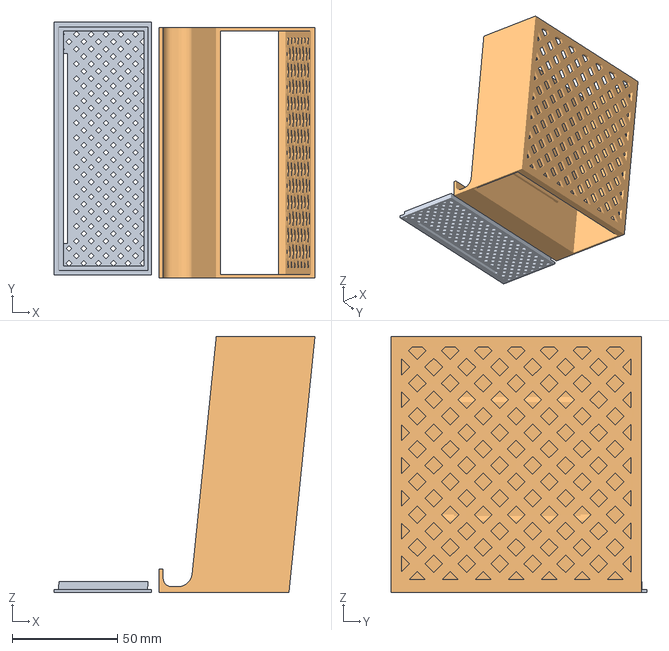
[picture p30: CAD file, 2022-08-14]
3D/STL/container/container.new.amf
123.7 x 121.3 x 121.4 mm

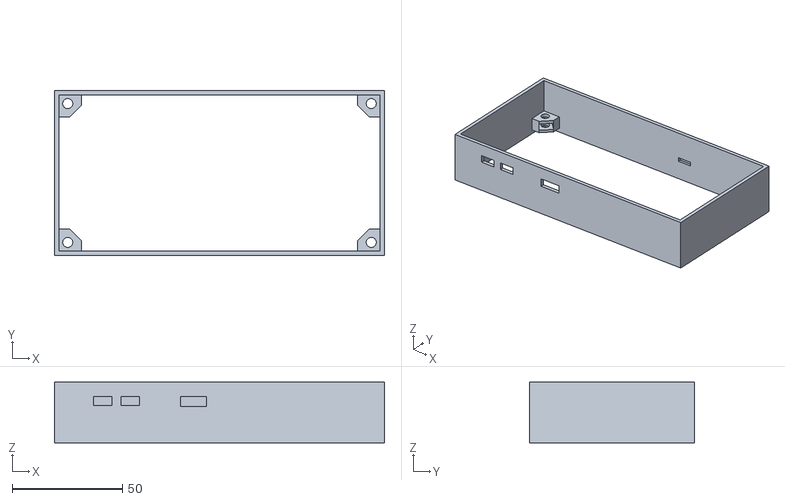
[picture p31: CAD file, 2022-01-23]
3D/STL/controlbox/controlbox-frame.stl
150.0 x 75.1 x 27.5

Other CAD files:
3D/FREECAD/overflow/overflow.plug.FCStd
3D/STL/lamp.hanger/lamp.hanger_console_extention.3mf
3D/STL/pipe/spillway.reducer.FCStd
3D/STL/round.container.hanger/Round.Container.Hanger.118mm.3mf
3D/FREECAD/a.FCStd
3D/FREECAD/camera/camera.FCStd
3D/FREECAD/camera/camera.new.FCStd
3D/FREECAD/camera/camera.wroover.FCStd
3D/FREECAD/cone.FCStd
3D/FREECAD/container.FCStd
3D/FREECAD/container.v3.FCStd
3D/FREECAD/container.v4.FCStd
3D/FREECAD/hanger.sonic.sensor.FCStd
3D/FREECAD/lamp/lamp.hanger.new.FCStd
3D/FREECAD/lamp/tmp.FCStd
3D/FREECAD/lamp/tmp2.FCStd
3D/FREECAD/lamp/tmp3.FCStd
3D/FREECAD/overflow-8.6_9.2.FCStd
3D/FREECAD/overflow/overflow-8.6_9.2.saved.FCStd
3D/FREECAD/overflow/overflow-8.8_9.2.FCStd
3D/FREECAD/overflow/overflow.cap.FCStd
3D/FREECAD/pipe.clamp.FCStd
3D/FREECAD/sonic.sensor.FCStd
3D/FREECAD/sonic.sensor.V2.FCStd
3D/FREECAD/sonic.sensor.V3.FCStd
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

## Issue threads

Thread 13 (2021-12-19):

Create function for start pumping.

dallaszkorben, 2021-12-19:
- [ ] Phase 1. Manual start

- [ ] Phase 2. Automatic start

1. Need a mark for the main tank
2. Check if the main tank has water
3. Note the levels before pump
4. Start pumping
    1 minute pump
    wait until the next report
    if the new level is still low and there is water in the main tank, repeat
     if the levels 1. higher than the start level + 2. are not changing, the water pumping is done

      if the main tank is too low -> alert
      if too many loops, stop and -> alert

Closed 2022-06-14.

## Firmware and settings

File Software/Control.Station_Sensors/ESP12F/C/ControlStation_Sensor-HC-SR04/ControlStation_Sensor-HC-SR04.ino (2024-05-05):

#include <ESP8266WiFi.h>        //WiFI related functionalities
#include <ESP8266WebServer.h>   //Handles HTTP protocols
#include <ESP8266HTTPClient.h>
#include <WiFiClient.h>
#include <Preferences.h>

#define MAX_RECONNECTION_LOOP 50
#define LED_INITIATE 0
#define LED_COMMUNICATE 1
#define LED_HEALTHY 2
#define LED_ERROR 3

int ledStatus = LED_INITIATE;
/*
 * Call services:
 *    curl -s --request GET http://192.168.50.101:80/all/aggregated
 *    curl -s --request GET http://192.168.50.101:80/all/actual
 *    curl -s --request GET http://192.168.50.101:80/pressure
 *    curl -s --request GET http://192.168.50.101:80/temperature
 *    curl -s --request GET http://192.168.50.101:80/humidity
 *    curl -s --request GET http://192.168.50.101:80/distance
 *    curl -s --request GET http://192.168.50.101:80/duration
 *    
 *    curl -s --request POST --header "Content-Type: application/json" http://192.168.50.101:80/configure --data {"stationId": "S02"} 
 * 
 * Continously read the values from this module on the same network:
 *    for i in $(seq 1 10000); do echo -n "$i `date -I'seconds'`: "; result=`curl -s -w "%{http_code}"  --max-time 20 http://192.168.50.101:80/all/aggregated `; code=`echo $result|grep -Po "\\d{3}$"`; if [[ $code == "200" ]] ; then echo $result; else echo $code; continue; fi; sleep 20; done\
 * 
 * Continously read the duration from this module on the same network:
 *    watch 'curl -s --header "Content-Type: application/json" --request GET http://192.168.50.112:80/duration | grep -oP "duration\":\"\d+[.]\d+"'
 */
const String version = "CS-0.0.3-1";

const char* ssid = "Central-Station-006";
const char* password = "viragfal";
const int serverPort = 80;

// --- Default values for Preferences ---
const bool          DEFAULT_NEED_TO_REPORT = true;
const bool          DEFAULT_NEED_TO_RESET = false;

const String        DEFAULT_CLIENT_IP   = "192.168.0.104";
const String        DEFAULT_CLIENT_PORT = "80";

const String        DEFAULT_CLIENT_PATH_TO_REGISTER = "sensor/register";
const String        DEFAULT_CLIENT_PATH_TO_REPORT   = "sensor/add";
const String        DEFAULT_CLIENT_PATH_TO_INFO_TIMESTAMP = "info/timeStamp";

const String        DEFAULT_STATION_ID                = "S04";
const unsigned long DEFAULT_INTERVAL_REPORT_MILLIS    = 600300;              // 10 min
const unsigned long DEFAULT_INTERVAL_REGISTER_MILLIS  = 120600;              // 2 min
const unsigned long DEFAULT_INTERVAL_RESET_MILLIS     = 3600900;             // 60 min
const unsigned long DEFAULT_INTERVAL_CONNECTION_MILLIS= 60200;               // 1 min
const int           DEFAULT_SENSOR_TEMPHUM_OUT_GPIO   = 0;
const int           DEFAULT_SENSOR_DISTANCE_ECHO_GPIO = 14;
const int           DEFAULT_SENSOR_DISTANCE_TRIG_GPIO = 12;

const double        DEFAULT_SENSOR_DISTANCE_PARAMETER_A = 0.0;
const double        DEFAULT_SENSOR_DISTANCE_PARAMETER_B = 0.017171;
const double        DEFAULT_SENSOR_DISTANCE_PARAMETER_C = 0.0;

// --- Preferences values ---
unsigned long intervalReportMillis      = 0;
long intervalRegisterMillis             = 0;
unsigned long intervalResetMillis       = 0;
unsigned long intervalConnectionMillis  = 0;

bool   needToReset  =     DEFAULT_NEED_TO_RESET;
bool   needToReport =     DEFAULT_NEED_TO_REPORT;
String stationId    =     "";

int    sensorTempHumOutGPIO   = NULL;
int    sensorDistanceEchoGPIO = NULL;
int    sensorDistanceTrigGPIO = NULL;

double  sensorDistanceParA = 0.0;
double  sensorDistanceParB = 0.0;
double  sensorDistanceParC = 0.0;

String clientIp   = "";
String clientPort = "";

String clientPathToRegister;
String clientPathToReport;
String clientPathToInfoTimestamp;

String timeOffsetString;
int timeOffsetInt;

// ---

double avgBmpTempCounter  = 0;
double avgBmpPressCounter  = 0;
double avgBmpTemp     = NULL;
double avgBmpPress    = NULL;
bool isSensorBmp;

double avgDhtTempCounter  = 0;
double avgDhtHumCounter  = 0;
double avgDhtTemp     = NULL;
double avgDhtHum      = NULL;

double avgHcsrCounter = 0;
double avgHcsrDist    = NULL;

//--- define functions ---
bool registerSensorStation(bool needToPrint);
bool reportSensors(bool needToPrint);

void ledSignalInitiate();
void ledSignalNetworkError();
void ledSignalCommunicate();
void ledSignalHealthy();

double getAvgTemp();
void setupVariables();
void wifiEvent(WiFiEvent_t event);
bool connectToAccessPoint(bool needToPrint);

bool configureDistanceSensor();
double getDuration(bool needToPrint);
double getDistanceByDuration(double duration);
double getSampleOfDistance(int sample);
double add1SampleToMovingAverageDistance(bool reset);

bool configureTempHumSensor();
struct DHT_Struct getTempHum(bool needToPrint);
struct DHT_Struct getSampleOfTempHum(int sample);
struct DHT_Struct add1SampleToMovingAverageTempHum(bool reset);

bool configurePressTempSensor();
struct BMP180_Struct getPressTemp(bool needToPrint);
struct BMP180_Struct getSampleOfPressTemp(int sample);
struct BMP180_Struct add1SampleToMovingAveragePressTemp(bool reset);

bool configureHttpServer();

Preferences stationPref;

ESP8266WebServer server(serverPort); //Server on port 80
WiFiClient client;
HTTPClient http;

struct DHT_Struct {
  double humidity;
  double temperature;
};

struct BMP180_Struct {
  double pressure;
  double temperature;
};

int loopCounter;
int numberOfMeasure;
unsigned long previousConnectionMillis;
long previousRegisterMillis;
unsigned long previousReportMillis;
unsigned long currentMillis;

void setup() {
    Serial.begin(115200);
    Serial.println("\n");
    delay(2000);

    pinMode(LED_BUILTIN, OUTPUT);  
    ledSignalInitiate();

    // --- Read Persistent Data --- //
    setupVariables();

    Serial.println();
    Serial.println("===== Connect to acceess Point =====");  
    Serial.println("Module information:");
    Serial.print("   MAC: ");
    Serial.println(WiFi.macAddress());

    //WiFi.disconnect();
    delay(1000);
    WiFi.onEvent(wifiEvent);
    WiFi.mode(WIFI_STA);
    WiFi.begin(ssid, password);    
    Serial.print("   SSID: ");
    Serial.println(WiFi.SSID());
    Serial.print("   RSSI: ");
    Serial.println(WiFi.RSSI());

    // --- Connect to Access Point --- ///
    if(!connectToAccessPoint(false)){
      ledSignalInitiate();
      Serial.println();
      Serial.println();
      Serial.println("!!! Must be restarted !!!");
      Serial.println();
      Serial.println();
      delay(10000);
      ESP.restart();
    }
    WiFi.setAutoReconnect(true);
    WiFi.persistent(true);
    WiFi.setSleep(false);

    Serial.print("   IP address: ");
    Serial.println(WiFi.localIP());
    Serial.println("====================================");
    Serial.println();

    // --- Sync Time --- //
    if( !syncTime() ){
      Serial.println("    !!! Sync Time failed -> reboot !!!");  
      delay(10000); 
      ESP.restart();
    }

    Serial.println("======== Configure Sensors =========");

    // --- Configure Pressure Temperature sensor --- //
    if( !configurePressTempSensor()){
      Serial.println("!!! Not possible to configure Pressure/Temperature Sensor. It will be ignored !!!");      
      Serial.println();
    }

    // --- Configure Temperature Humidity sensor --- //
    if( !configureTempHumSensor()){
      Serial.println("!!! Not possible to configure Temperature/Humidity Sensor. It will be ignored !!!");
      Serial.println();
    }

    // --- Configure Distance sensor --- //
    if( !configureDistanceSensor()){
      Serial.println("!!! Not possible to configure Sonic Sensor. It will be ignored !!!");
      Serial.println();
    }
    Serial.println("====================================");
    Serial.println();

    // --- Configure HTTP server --- //
    Serial.println("========= Start WEB server =========");
    if( !configureHttpServer()){
      ledSignalNetworkError();
      Serial.println("!!! Not possible to configure HTTP server. The Module will be restarted !!!");
      Serial.println();
      Serial.println();
      delay(10000);
      ESP.restart();
    } 
    Serial.printf("Web server started, open %s in a web browser\n", WiFi.localIP().toString().c_str());
    Serial.println("====================================");
    Serial.println();

    ledSignalHealthy();

    //Serial.setDebugOutput(true);

  loopCounter = 0;
  numberOfMeasure = 30;
  previousConnectionMillis = millis();
  previousRegisterMillis = -(intervalRegisterMillis); //Reason to fill up with the -interval length is to take sample at the first time in the loop
  previousReportMillis = millis();                    
  currentMillis = millis();                           
}

void loop() {
  
  int actualMeasureLoop = loopCounter % numberOfMeasure; //range: 0-29. In the first 0. 1. 2. loop will be taken 1-1 sample
  loopCounter++;

  ///////////////////////////////////
  // BMP180 - Pressure + Temperature
  ///////////////////////////////////
  // Tries to take Pressure/Temperture sample in every 0. loop
  if(actualMeasureLoop == 0){    
    struct BMP180_Struct bmp180Result = add1SampleToMovingAveragePressTemp(false);
  }
  
  ///////////////////////////////////
  // DHT - Temperature + Humidity
  ///////////////////////////////////
  // Tries to take Temperature+mumidity sample in every 1. loop
  if(actualMeasureLoop == 1){    
    struct DHT_Struct dhtResult = add1SampleToMovingAverageTempHum(false);
  }
  
  ///////////////////////////////////
  // HCSR04 - Distance
  ///////////////////////////////////
  // Take Distance sample in every 2. loop
  if(actualMeasureLoop == 2){    
    double hcsrResult = add1SampleToMovingAverageDistance(false);
  }

  currentMillis = millis();

  // --------------------------------------------
  //
  //In every 60 seconds (1min) checks if there is connection
  //
  // --------------------------------------------
  if(currentMillis - previousConnectionMillis >= intervalConnectionMillis){
    ledSignalCommunicate();
    if(!connectToAccessPoint(false)){
      Serial.println("!!! Must be restarted !!!");
      Serial.println();
      Serial.println();
      ESP.restart();
    }else{
//      Serial.print("Connection is OK: ");
//      Serial.println(WiFi.localIP());
    }
    ledSignalHealthy();
    previousConnectionMillis = currentMillis;     
  }
  
  // --------------------------------------------
  //
  //In every 120 seconds (2min) tries to REGISTER
  //
  // --------------------------------------------
  if(currentMillis - previousRegisterMillis >= intervalRegisterMillis){
    ledSignalCommunicate();   
    if ( registerSensorStation(false) ){
      Serial.print("Sensor Station was registered at "); 
      Serial.println(getOffsetDateString());
Serial.print(avgHcsrDist);      
Serial.print(" = ");      
Serial.println(avgHcsrCounter);       
      previousRegisterMillis = currentMillis;      
    }else{
      ledSignalNetworkError();
      Serial.print("!!! Sensor Station register failed at");
      Serial.println(getOffsetDateString());
      delay(1000);
    } 
    ledSignalHealthy();
  }
  
  // --------------------------------------------
  //
  //In every 600 seconds (10min) tries to REPORT
  //
  // --------------------------------------------

//  Serial.print(currentMillis); 
//  Serial.print("-");
//  Serial.print(previousReportMillis); 
//  Serial.print(">=");
//  Serial.println(intervalReportMillis); 

  if(needToReport && (currentMillis - previousReportMillis >= intervalReportMillis)){

    ledSignalCommunicate();

Serial.print(avgHcsrDist);
Serial.print(" = ");
Serial.print(avgHcsrCounter);
Serial.println("   ");

    if ( reportSensors(false) ){
      Serial.print("Sensors was reported at "); 
      Serial.println(getOffsetDateString());
      previousReportMillis = currentMillis;
      delay(5000);
    }else{
      ledSignalNetworkError();
      Serial.print("!!! Sensors report failed at: ");   
      Serial.println(getOffsetDateString());
      delay(2000);
    } 
    ledSignalHealthy();

//    Serial.println();   
  }

  // --------------------------------------------
  //
  //In every 3600 seconds (1hour) RESTART
  //
  // --------------------------------------------
  if(currentMillis >= intervalResetMillis){
    Serial.println();
    Serial.println("==========================");
    Serial.println("===  !!!  RESET   !!!  ===");
    Serial.println("===      general       ===");
    Serial.println("==========================");
    Serial.println();
    ESP.reset();
  }

  server.handleClient();          //Handle client requests

  delay(10);
}

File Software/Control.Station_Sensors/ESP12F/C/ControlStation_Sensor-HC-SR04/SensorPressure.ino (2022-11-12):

// BMP180_I2C
//
// connect the BMP180 to the Arduino like this:
// Arduino - BMC180
// 5V ------ VCC
// GND ----- GND
// SDA ----- SDA
// SCL ----- SCL

#include <Arduino.h>
#include <Wire.h>
#include <BMP180I2C.h>

#define I2C_ADDRESS 0x77

//create an BMP180 object using the I2C interface
BMP180I2C bmp180(I2C_ADDRESS);

bool configurePressTempSensor(){
  bool ret = true;

  Wire.begin();

  //begin() initializes the interface, checks the sensor ID and reads the calibration parameters.  
  if (!bmp180.begin()) {
    Serial.println();
    Serial.println("!!! bmp180.begin() failed. check your BMP180 Interface and I2C Address !!!");
    isSensorBmp = false;
    ret = false;

  }else{

    //reset sensor to default parameters.
    bmp180.resetToDefaults();

    //enable ultra high resolution mode for pressure measurements
    bmp180.setSamplingMode(BMP180MI::MODE_UHR);
  
    isSensorBmp = true;
    Serial.println("   BMP Pressure Sensor has been Configured");

  }
  return ret;
}

/*
 * 
 */
struct BMP180_Struct getPressTemp(bool needToPrint){
  struct BMP180_Struct ret;
  ret.temperature = NULL;
  ret.pressure = NULL;

  if(!isSensorBmp){
    return ret;
  }

  //start a temperature measurement
  if (!bmp180.measureTemperature()){
    if(needToPrint){
      Serial.println("!!! could not start temperature measurement, is a measurement already running?");
    }  
  }else{

    //wait for the measurement to finish. proceed as soon as hasValue() returned true. 
    int searchLoop = 0;
    do{
      delay(100);
      searchLoop++;
    } while (!bmp180.hasValue() && searchLoop < 20);

    // Could measure Temperature
    if(searchLoop < 20){
      ret.temperature = bmp180.getTemperature();   

      if(needToPrint){
        Serial.print("Temperature: "); 
        Serial.print(ret.temperature); 
        Serial.println(" degC");
      }
    }
  }
  
  //start a pressure measurement. pressure measurements depend on temperature measurement, you should only start a pressure 
  //measurement immediately after a temperature measurement. 
  if (!bmp180.measurePressure()){
    if(needToPrint){
      Serial.println("could not start perssure measurement, is a measurement already running?");    
    }
  }else{

    //wait for the measurement to finish. proceed as soon as hasValue() returned true. 
    int searchLoop = 0;
    do {
      delay(100);
      searchLoop++;
    } while (!bmp180.hasValue() && searchLoop < 20);

    // Could measure Temperature
    if(searchLoop < 20){
      ret.pressure = bmp180.getPressure();
  
      if(needToPrint){
        Serial.print("Pressure: "); 
        Serial.print(ret.pressure);
        Serial.println(" Pa");
      }
    }
  }
  return ret;  
}

struct BMP180_Struct getSampleOfPressTemp(int sample){
  struct BMP180_Struct ret;
  double sumTemp = 0;
  double sumPress = 0;
  double incTemp = 0;
  double incPress = 0;  
  double actualTemp;
  double actualPress;

  struct BMP180_Struct result;
  
  for(int i = 0; i < sample; i++){
    result = getPressTemp(false);
    actualTemp = result.temperature;
    actualPress = result.pressure;

    if(actualTemp != NULL){
      sumTemp += actualTemp;
      incTemp++;
    }
    if(actualPress != NULL){
      sumPress += actualPress;
      incPress++;
    }
  }

  if(incTemp > 0){
    ret.temperature = sumTemp/incTemp;
  }else{
    ret.temperature = NULL;
  }

  if(incPress > 0){
    ret.pressure = sumPress/incPress;
  }else{
    ret.pressure = NULL;
  }
  
  return ret;
}


/********************************************************
*
* Dinamically calculate average (moving average) Pressure/Temperature
* The calculated average Press/Temp are stored in the avgBmpPress/avgBmpTemp 
* variable.
* When you call this function, it will take a new Press/Temp 
* measurement and calculates new average value including
* this new value.
* 
* Calculation of moving average:
*    N = 0
*    avg = 0
*    
*    For each new value: V
*        N=N+1
*        a = 1/N
*        b = 1 - a
*        avg = a * V + b * avg
*        
*********************************************************/
struct BMP180_Struct add1SampleToMovingAveragePressTemp(bool reset){
  struct BMP180_Struct ret;
  double actualTemp;
  double actualPress;

  ret.temperature = NULL;
  ret.pressure = NULL;

  if(reset){
    avgBmpTemp = NULL;
    avgBmpPress = NULL;
    avgBmpTempCounter = 0;
    avgBmpPressCounter = 0;
  }

  if (!isSensorBmp){
    return ret;
  }
  
  struct BMP180_Struct result;
  result = getSampleOfPressTemp(1);
 
  actualTemp = result.temperature;
  actualPress = result.pressure;

  // ---

  if(actualTemp != NULL && avgBmpTemp != NULL){
    avgBmpTempCounter++;
    double a = 1/avgBmpTempCounter;
    double b = 1 - a;
    avgBmpTemp = a * actualTemp + b * avgBmpTemp;
  }else if(actualTemp != NULL){
    avgBmpTempCounter = 1;
    avgBmpTemp = actualTemp;
  // If the recent measurement was not evaluable
//  }else{
//    avgBmpTempCounter = 0;
//    avgBmpTemp = NULL;
  }

  // ---

   if(actualPress != NULL && avgBmpPress != NULL){
    avgBmpPressCounter++;
    double a = 1/avgBmpPressCounter;
    double b = 1 - a;
    avgBmpPress = a * actualPress + b * avgBmpPress;
  }else if(actualPress != NULL){
    avgBmpPressCounter = 1;
    avgBmpPress = actualPress;
  // If the recent measurement was not evaluable
//  }else{
//    avgBmpPressCounter = 0;
//    avgBmpPress = NULL;
  }

  // ---

  ret.temperature = avgBmpTemp;
  ret.pressure = avgBmpPress;

  return ret; 
}

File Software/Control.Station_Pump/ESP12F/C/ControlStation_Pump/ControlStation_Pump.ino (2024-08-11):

#include <ESP8266WebServer.h>
#include <ESP8266HTTPClient.h>
#include <ESP8266WiFi.h>
#include <ArduinoJson.h>
#include <TimeLib.h>
#include "FS.h"

HTTPClient http;
WiFiClient wifiClient;
ESP8266WebServer server(80);

// --- Config file ---
String essid;
String password;
String webserver_ip;
String webserver_path_info_timestamp;
String webserver_path_pump_register;
String webserver_path_info_is_alive;

String pump_id;
int pump_gpio;
int led_status_gpio;
int led_status_inverse;
int register_interval_sec;
int regular_reset_seconds;

bool pumpActive = false;

#define LED_INITIATE 0
#define LED_COMMUNICATE 1
#define LED_HEALTHY 2
#define LED_ERROR 3

int ledStatus = LED_INITIATE;

bool healthy = true;
long syncTimestamp = 0;
long regTimestamp = 0;
long resetTimestamp = 0;

String timeOffsetString;
int timeOffsetInt;

bool pump_active = false;
long pump_start_timestamp = 0;
long pump_off_timestamp = 0;

// -------------------

void setup() {
  Serial.begin(115200);
  Serial.println("\n");
  delay(2000);

  pinMode(LED_BUILTIN, OUTPUT);  

  ledSignalInitiate();
  
  // --- Config --- //
  Serial.println("========== Setup ==========");
  Serial.println("vvv Reading Config file vvv");

  if(!SPIFFS.begin()){
    Serial.println("Failed to mount file system");
    Serial.println("!!! Wait 10 seconds and then restart !!!");
    delay(10000);
    ESP.restart();
  }

  if(!loadConfig()){
    Serial.println("Failed to load config");
    return;
  }else{
    Serial.println("^^^    Config loaded    ^^^\n");    
  }

  // --- Connect to WiFi --- //
  connectToWiFi();

  // --- Sync Time --- //
  if( !syncTime() ){
    ledSignalNetworkError();
    Serial.println("==========================");
    Serial.println("===   !!!  RESET  !!!  ===");
    Serial.println("===  Failed Sync Time  ===");
    Serial.println("==========================");
    ESP.restart();
  }

  // --- Configure and Register Pump --- //
  pinMode(pump_gpio, OUTPUT);

  if( !registerPump() ){
    ledSignalNetworkError();
    Serial.println("======================================");
    Serial.println("===        !!!  RESET  !!!         ===");
    Serial.println("===  Failed to register PUMP  ===");
    Serial.println("======================================");
    delay(60000);
    ESP.restart();
  }

  // --- Web Server --- //
  server.on("/isAlive", HTTP_GET, handleIsAlive );
  server.on("/pump/status", HTTP_GET, handlePumpStatus);
  server.on("/pump/off", HTTP_POST, handlePumpOff);
  server.on("/pump/on", HTTP_POST, handlePumpOn);
  server.onNotFound(handleNotFound);
  server.begin();
  Serial.println("HTTP server started\n");

  // --- Sync Pump statuses -- //
  /*if (!syncPumpStatus()){
    ledSignalNetworkError();
    Serial.println("==================================");
    Serial.println("===       !!!  RESET  !!!      ===");
    Serial.println("===    Failed to Sync Pump     ===");
    Serial.println("==================================");
    delay(60000);
    ESP.restart();
  }*/

  ledSignalHealthy();

  long now_tstmp = now();
  resetTimestamp = now_tstmp + regular_reset_seconds;
  Serial.println("==================================");
  Serial.println("===   !!! Reset Config !!!    ====");
  
  Serial.print("=== Now: ");
  Serial.println(now_tstmp);
  Serial.print("=== Delta: ");
  Serial.println(regular_reset_seconds);  
  Serial.print("=== Next reset: ");
  Serial.println(resetTimestamp);
  Serial.println("==================================");

  Serial.println("\n============== setup() finished =================\n\n");

}

void loop() {

  server.handleClient();

  // in every seconds
  if (syncTimestamp != now()){
    syncTimestamp = now();  

    // If the pump is ON, in every 10 seconds it tries to sync it.
    if(pump_active && syncTimestamp%1 == 0){
      syncPumpStatus();

    // contradiction => turn off pump
    }else if(pump_off_timestamp != 0){
      turnPumpOff();
    }
  }

  // reset_hours
  if (now() > resetTimestamp){
    Serial.println("=========================");
    Serial.println("===  !!!  RESET  !!!  ===");
    Serial.println("===      Regular      ===");
    Serial.print(  "=== Time: ");
    Serial.print(now());
    Serial.println("  ===");
    Serial.println("=========================");
    ESP.reset();    
  }

  // in every seconds
  if (regTimestamp != now()){

    // If there is WiFi connection
    if( WiFi.localIP().isSet() and WiFi.isConnected() ){

      regTimestamp = now();  

      // in every 30 seconds it tries to register
// !!! register_interval_sec must me used instead of hardcoded 30 //
      if( regTimestamp%30 == 0 ){
        if( !registerPump()){
          healthy = false;
        }else{
          healthy = true;
        }
      }
    }else{
      //healthy = false;
    }
  }

  if( healthy && ledStatus == LED_ERROR){
    Serial.print("changed to HEALTHY - healthy: ");
    Serial.print(healthy);
    Serial.print(" ledStatus: ");
    Serial.println(ledStatus);
    
    ledSignalHealthy();
  }else if(!healthy && ledStatus == LED_HEALTHY){
    Serial.print("changed to ERROR - healthy: ");
    Serial.print(healthy);
    Serial.print(" ledStatus: ");
    Serial.println(ledStatus);

    ledSignalNetworkError();
  }
  
}

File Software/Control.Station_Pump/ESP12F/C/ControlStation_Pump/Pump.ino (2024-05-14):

#define PUMP_STATUS_FILE_NAME "/pump_status.json"
#define MAX_STATUS_SIZE 1024

void turnPumpOn(){
  digitalWrite(pump_gpio, HIGH);
  return;
}

//bool setPumpStatusFile(StaticJsonDocument<1024> doc, bool active, long timestamp){
bool setPumpStatusFile(bool active, long timestamp){
  bool result = false;

// ---

  File statusFileToRead = SPIFFS.open(PUMP_STATUS_FILE_NAME, "r");
  if(!statusFileToRead){
    Serial.println("Failed to open pump status file for reading");
    return result;
  }

  size_t size = statusFileToRead.size();
  if(size > MAX_STATUS_SIZE){
    statusFileToRead.close();
    Serial.println("Pump status file size is too large");
    return result;
  }

  Serial.print("Get pump status file. Size: ");
  Serial.println(size);

  std::unique_ptr<char[]> buf(new char[size]);
  statusFileToRead.readBytes(buf.get(), size);  
  Serial.println(buf.get());

  StaticJsonDocument<1024> doc;
  DeserializationError error = deserializeJson(doc, buf.get());

  if(error){
    Serial.print("Failed to parse pump status file: ");
    Serial.println(error.c_str());
    return result;
  }

  statusFileToRead.close();

// ---

  Serial.println("Set pump status file");
  
  doc["active"] = active;
  doc["off-timestamp"] = timestamp;

  File statusFileToWrite = SPIFFS.open(PUMP_STATUS_FILE_NAME, "w");
  if( !statusFileToWrite){
    Serial.println("Failed to open pump status file");
      return result;
  }

  serializeJsonPretty(doc, Serial);
  Serial.println();
  
  serializeJsonPretty(doc, statusFileToWrite);
  statusFileToWrite.close();
  result = true;
  return result;
}


bool syncPumpStatus(){

  Serial.println("Sync Pump status");
  bool result = false;

//  File statusFile = SPIFFS.open(PUMP_STATUS_FILE_NAME, "r");
//  if( !statusFile){
//    Serial.println("Failed to open pump status file for reading");
//    return result;
//  }
//
//  size_t size = statusFile.size();
//  if(size > MAX_STATUS_SIZE){
//    statusFile.close();
//    Serial.println("Pump status file size is too large");
//    return result;
//  }
//
//  Serial.print("  Config file size: ");
//  Serial.println(size);
//
//  std::unique_ptr<char[]> buf(new char[size]);
//  statusFile.readBytes(buf.get(), size);  
//  Serial.println(buf.get());
//
//  StaticJsonDocument<1024> doc;
//  DeserializationError error = deserializeJson(doc, buf.get());
//
//  if(error){
//    Serial.print("Failed to parse pump status file: ");
//    Serial.println(error.c_str());
//    return result;
//  }
//
//  statusFile.close();
//
//  pump_active = doc["active"];
//  pump_off_timestamp = doc["off-timestamp"];

  long now_timestamp = now();

  if (pump_off_timestamp > now_timestamp){
      Serial.print("The pump still should run until ");
      Serial.print(pump_off_timestamp - now_timestamp);
      Serial.println(" seconds, so it will be turned on...");
      turnPump(HIGH);
      pump_active = true;
  }else{
      Serial.println("The pump should stop, so it will be turned off...");

//      doc["active"] = false;
//      doc["off-timestamp"] = 0;
//
//      File statusFileToWrite = SPIFFS.open(PUMP_STATUS_FILE_NAME, "w");
//      if( !statusFileToWrite){
//        Serial.println("Failed to write pump status");
//        return result;
//      }
//
//      serializeJsonPretty(doc, statusFileToWrite);
//      statusFileToWrite.close();
//
//      turnPump(LOW);

    turnPumpOff();
  }
  
  result = true;
  return result;  
}

bool turnPumpOn(int lengthInSec){
  pump_active = true;
  pump_start_timestamp = now();
  pump_off_timestamp = pump_start_timestamp + lengthInSec;
  turnPump(HIGH);

  return true;
}

void turnPumpOff(){
  turnPump(LOW);
  pump_active = false;
  pump_start_timestamp = 0;
  pump_off_timestamp = 0;
  
  return;
}

void turnPump(int status){
  digitalWrite(pump_gpio, status);
}

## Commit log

2021-09-19 Level-Station communication with Center-Station
    [pipe.clamp-curve.1.part.stl, pipe.clamp-curve.2.parts.stl, pipe.clamp-frane.stl]
2021-09-27 Fix signaling on the built in LED
    [sonic.sensor.V2.FCStd, sonic.sensor.V2.stl, sonic.sensor.cover.V2.stl]
2021-10-14 Code-fix connection problems
    [sonic.sensor.V2.FCStd, sonic.sensor.V2.stl, sonic.sensor.V3.FCStd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]
2021-10-26 2 type of approaches
    Central=Access Point - Level=Station
    Central=Station - Level=Access Point
    [sonic.sensor.V3.FCStd, sonic.sensor.all.stl, sonic.sensor.cap.stl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]
2021-11-01 Fixed LevelStation ESP-12 aligned to Raspberry
    [sonic.sensor.V4.FCStd]
2021-11-02 Level-station code alligned to the change in Raspberry code
2021-11-06 Update README.md
    Raspberry PI configuration - AP
2021-11-12 Calibrate to Ultrasonic sensor
2021-11-13 Calibrate Ultrasonic Sensor with Quadratic regression
    [sonic.sensor.V2.FCStd, sonic.sensor.V5.FCStd, sonic.sensor.all.stl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]
2021-11-21 #4 - sync time and send the actual time in the requests
    [sonic.sensor.V5.FCStd, sonic.sensor.all.stl, sonic.sensor.cap.stl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]
2021-12-04 Water level and Temperature on the browser
2021-12-05 Water level, Temperature, Humidity shown on web portal
2021-12-05 Station - collect temperature and humidity
    [hanger.sonic.sensor.FCStd, hanger.sonic.sensor.stl, sonic.sensor.V5.FCStd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]
2021-12-12 Designe hanging level sensor
    [hanger.sonic.sensor.FCStd, hanger.sonic.sensor.V2.FCStd, hanger.sonic.sensor.v2.stl]
2021-12-18 #11-print out the sensor ID on web
2021-12-18 #9 check and handle if no sensor connected
2021-12-25 Introduce Rotary Encoder
2021-12-30 3D hanger station
    [hanger.sonic.sensor.V2.FCStd, hanger.sonic.sensor.v2.stl, hanger.station-main.frame.stl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]
2021-12-31 Print data to LCD display
2022-01-08 Introduce Pump control
2022-01-23 Introduce Control Station
    [a.FCStd, container-bottom.V2.stl, container-bottom.V3.stl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]
2022-02-13 Control.Station started using C
    With Micropython it was very unstable
    [SyncTime.ino, WebServer.ino, Wifi.ino]
2022-02-28 ControlStatus Pump
2022-04-12 3D ovreflow introduced
    [a.FCStd, cone.FCStd, container-bottom.V2.stl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]
2022-04-14 Introduce 3D watertank_clamp
    [overflow-8.6_9.2.FCStd, overflow-8.8_9.2.FCStd, overflow.FCStd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]
2022-04-15 3D develop overflow_ring
    [overflow-8.6_9.2.FCStd, overflow.stl, overflow_ring.stl]
2022-04-16 develop 3D: watertank_clamp
    [overflow-8.6_9.2.saved.FCStd, overflow-8.8_9.2.FCStd, water_tank.FCStd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]
2022-05-15 3D Control.Station, Lamp Control on web
    [camera.FCStd, camera.amf, camera.attached.to.lamp_esp32_wrover.amf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]
2022-05-15 Get Pump Status
2022-05-15 Pump Control
2022-05-18 Fix pump control on web
2022-05-26 Only the valid regisered lamp/pump will be considered
2022-05-26 Continously registering pump/lamp
    [camera.FCStd, camera.amf, camera.attached.to.lamp_reverse_camera.frame_esp32.wroover.amf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]
2022-06-09 Camera capture
    [container.amf]
2022-06-13 cam/frame/save server side
2022-06-13 /cam/frame/save client side
2022-07-03 multiple cameras. Attach and remove
2022-07-29 Capture images from the Frame => 1 image/minute The single Capture Page refreshes
2022-08-08 Step forth and back through the frames
2022-08-08 Frame Slide introduced
2022-08-09 FastForward/FastBackward on frame slide
2022-08-14 3D container-vertical
    [camera.FCStd, container-vertical.FCStd, container-vertical.amf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]
2022-08-27 3D lamp consoles and caps
    [control.station.50w.amf, control.station.clamp.amf, control.station.frame.50w.amf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]
2022-09-19 GET /cam/configure POST /cam/configure
    [camera.attached.to.lamp_reverse_camera.frame_esp32.wroover.amf, camera.attached.to.lamp_reverse_full_esp32.wroover.amf, camera.attached.to.lamp_reverse_lamp.co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]
2022-09-24 3D camera cover
    [camera.new.FCStd, camera.wroover.FCStd, camera.wroover.all.reverse.stl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]
2022-09-25 GET /configure POST /configure fix
    [ControlStation_Cam.ino, RegisterCam.ino]
2022-10-02 Sensor.Station C code started with pressure sensor
    [camera.wroover.FCStd, camera.wroover.console.long.stl, camera.wroover.nested.FCStd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]
2022-10-08 Station Sensor 3D and Code
    [camera.wroover.nested.FCStd, hanger.station.V2.FCStd, station.sensor.all.stl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]
2022-10-15 Introduce Report and LED blinking in the sensor
    [hanger.station-main.frame.stl, hanger.station-rail.stl, hanger.station-sonic.sensor.frame.stl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]
2022-10-15 Introduce Report Sensor on the server side
2022-10-16 Handle missing sensors
2022-10-19 Add ControlStation schematic
2022-10-19 add SensorStation readme
2022-10-24 Introduce POST /configure sensor
    [station.sensor.V2.FCStd, station.sensor.console.stl]
2022-10-30 Makes connection before starts HTTP server in Sensor station
2022-11-06 Introduce Sensor Register functionality
2022-11-06 Add Sensor register functionality to the Sensor Station
2022-11-12 Fix the moving average methods
    [ReportSensors.ino, SensorDistance.ino, SensorPressure.ino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]
2022-11-13 Distance calibration
2022-11-20 For test reason changed the ControlStation_sensor.ino and SensorDistance.ino
2024-04-14 get rid of text sensor_report
2024-04-21 trigger Report introduced
    [Round.Container.Hanger.118mm.3mf, Round.Container.Hanger.133mm.3mf, lamp.hanger.FCStd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]
2024-04-21 sensor register introduced
2024-04-22 Central.AccessPoint-RaspberryPi commit
2024-05-05 Fix the triggerReport solution
    [ControlStation_Sensor-HC-SR04.ino, HTTPServer.ino, PersistentData.ino]
2024-05-13 lot of changes
    [station.lamp.2x42v-YL401.3mf, station.lamp.pump.100W.FCStd]
2024-05-14 Pump chart with easy-pie-chart
2024-05-14 Fix in controlStation Lamp/Pump
    [ControlStation_Lamp_Pump.ino, Pump.ino, WebServer.ino]
2024-08-11 New frame for lamp and pump
    [station.lamp.1X42v-Button.stl, station.lamp.1X42v-Frame.stl, station.lamp.1X42v-Separator.stl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]
2024-08-11 handle multiple pumps and lamps
